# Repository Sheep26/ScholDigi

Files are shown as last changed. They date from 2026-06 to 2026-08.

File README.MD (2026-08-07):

# Why am I requesting funding again.
I am requesting funding again so I would be able to get a second revision of my board printed. I will mostly not be using PCBA so it'll be cheaper.  
The reason I need a second revision is because of my mistakes/errors, I left a few things out on the board (and also had a short which killed the GPS module).  
So I am requesting the funding for a new GPS module and to get a new board printed with space for more resistors, capacitors and more which I will solder myself.

# Scholarship Digitech.
This is my NZQA scholarship technology project.  
It is a small device which can fit in your pocket or bag, and will track your tramping, hiking, walking, running, cycling, skiing, etc.  
It uses a Ublox max-m10s gpu module on a fully custom pcb, with an esp32-c6, battery management system, power management system, serial connection and 2 usb ports for 2 different reasons (one is charging the other is flashing firmware which can also be done from testpoints in case there is too much signal interference).    

This project took inspration from apps such as Strava, however it aims to tackle one of the main issues with Strava which is the fact that it uses your phone. Strava is known to drain phone batteries and on many phones just not work well, this project aims to replace it with a dedicated device with a high accuracy GPS and long battery life allowing it to combat the various issues with fitness apps such as Strava.    

The purpose of this project, was to make an open source fitness tracker for cheap. The point is the motivate communities to improve their fitness and wellbeing without having them spend hundreds of dollars on something like a Garmin or Samsung smart watch and for it to be easy. Something small you can put in your pocket or bag which can last a long time on battery.  

## Hardware
Microcontroller | ESP32-C6-Mini  
GPS | Ublox MAX-M10S GPS module  
Battery management | TP4056 lithium battery charger  
Power management | TPS63060 voltage step down or step up buck converter  
CP2102 | Serial UART to USB  

(For a full list of hardware and pricing visit the BOM)



## Render
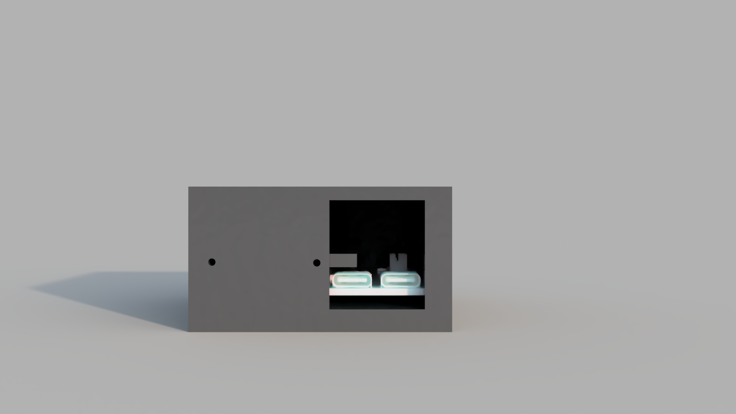
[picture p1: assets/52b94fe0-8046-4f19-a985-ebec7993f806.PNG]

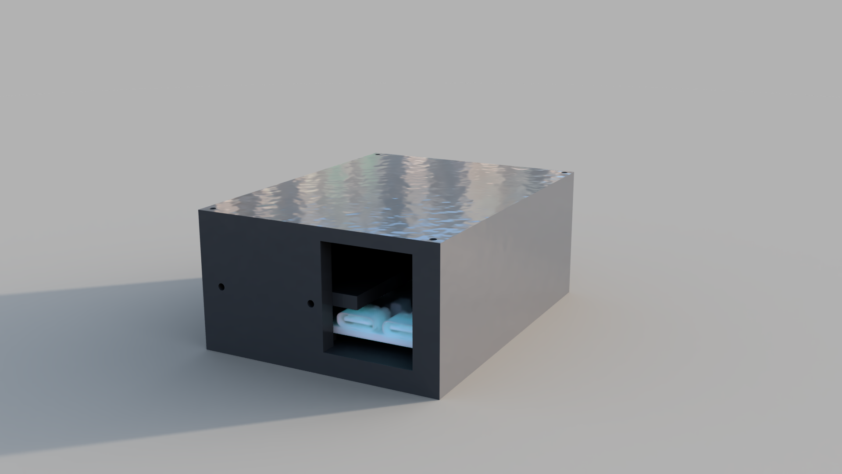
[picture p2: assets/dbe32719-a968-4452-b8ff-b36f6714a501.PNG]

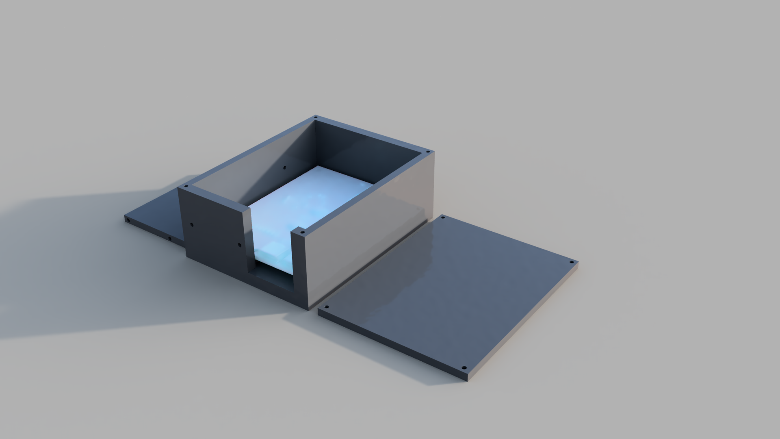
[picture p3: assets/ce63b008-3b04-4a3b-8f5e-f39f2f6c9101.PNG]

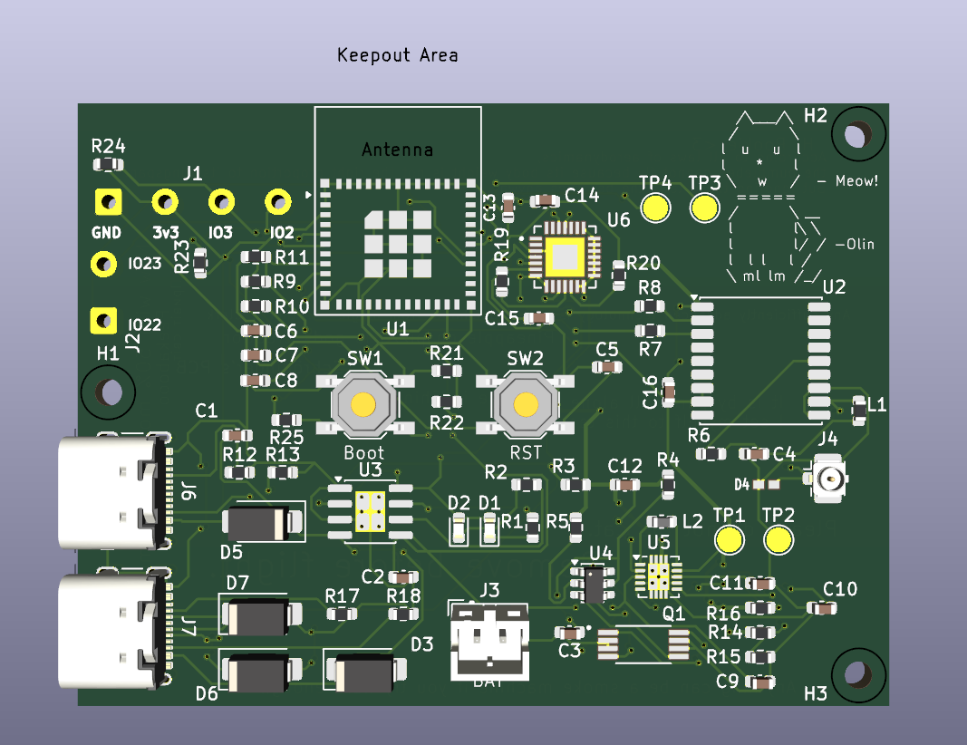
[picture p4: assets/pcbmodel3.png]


## Schematic
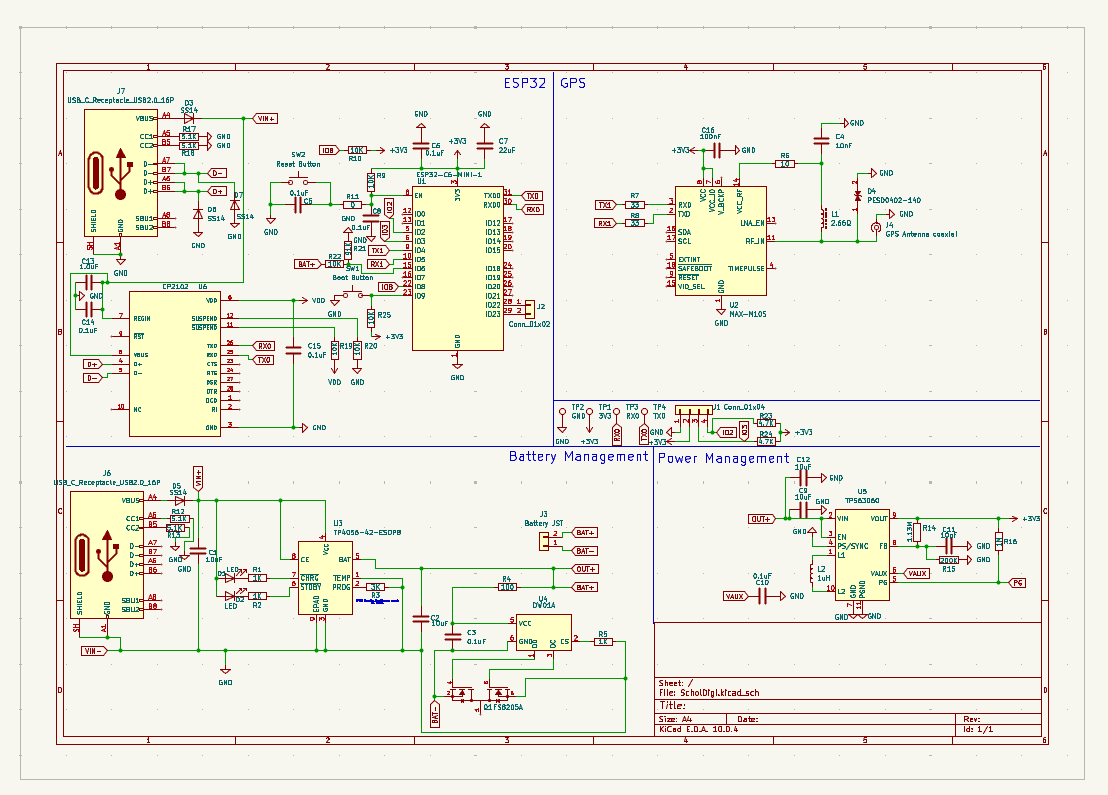
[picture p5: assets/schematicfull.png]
Schematic Image 1


## PCB
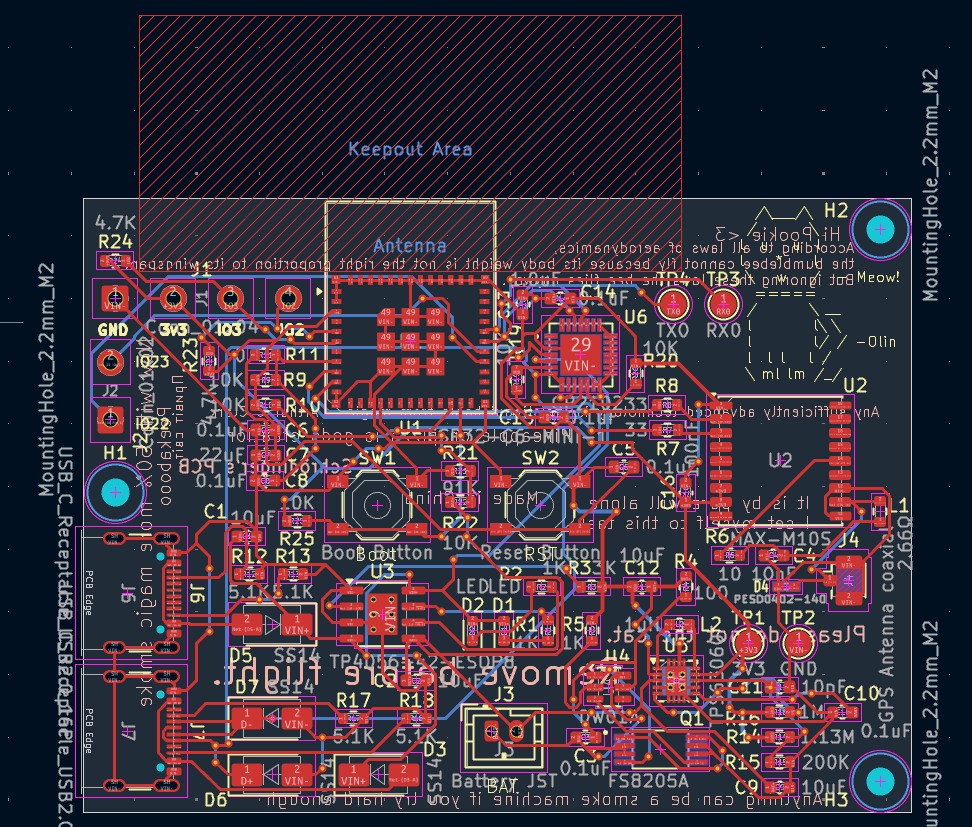
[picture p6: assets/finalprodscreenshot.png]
PCB Image 1


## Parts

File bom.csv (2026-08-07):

Type | PART | Qty | Source | Total Price ($)
PCB |  | 5 | JLCPCB | 2
PCBA |  | 5 | JLCPCB | 10.87
PCBTOTAL |  | 5 | JLCPCB | 12.87
SHIPPING |  | 1 | DHL EXPRESS | 16
PART | 1 | UBLOX MAX-M10S-00B | DIGIKEY | 12.29
SHIPPING | 1 |  | DHL EXPRESS | 15.23
GST | 1 |  |  | 4.13
PARTTOTAL |  |  |  | 31.68
TOTAL |  |  |  | 60.55

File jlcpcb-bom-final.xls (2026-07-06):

Comment | Designator | Footprint | JLCPCB Part # | Qty | Ext.Price($)
10nF | C4 | 0603 | C57112 | 20 | 0.16
10pF | C11 | 0603 | C1634 | 20 | 0.12
2.66Ω | L1 | 0603 | C113030 | 10 | 0.84
GPSAntennacoaxial | J4 | SMD | C88374 | 5 | 0.54
33 | R7,R8 | 0603 | C23140 | 20 | 0.04
0.1uF | C10,C14,C15,C3,C5,C6,C8 | 0603 | C14663 | 24 | 0.64
BatteryJST | J3 | 插件,P=2mm | C131337 | 3 | 0.10
USB_C_Receptacle_USB2.0_16P | J6,J7 | SMD | C5184243 | 4 | 4.64
LED | D1,D2 | 0603 | C2290 | 20 | 0.24
1uH | L2 | 0603 | C2839970 | 20 | 0.45
10uF | C1,C12,C2,C9 | 0603 | C19702 | 20 | 2.10
ResetButton | SW1,SW2 | SMD-4P,5.2x5.2mm | C2886894 | 4 | 2.68
CP2102 | U6 | - | C6568 | 2 | 4.39
PESD0402-140 | D4 | 0402 | C10662 | 5 | 0.71
SS14 | D3,D5,D6,D7 | SMA(DO-214AC) | C2480 | 18 | 0.32
10K | R10,R19,R20,R22,R9 | 0603 | C95204 | 20 | 0.59
200K | R15 | 0603 | C25811 | 20 | 0.05
5.1K | R12,R13,R17,R18 | 0603 | C23186 | 20 | 0.06
10 | R6 | 0603 | C22859 | 20 | 0.05
100 | R4 | 0603 | C22775 | 20 | 0.41
MAX-M10S | U2 | LCC-18(9.7x10.1) | C4153167 | 2 | 19.86
TP4056-42-ESOP8 | U3 | ESOP-8 | C16581 | 2 | 0.37
1.13M | R14 | 0603 | C166907 | 20 | 0.04
91K | R21 | 0603 | C101235 | 20 | 0.03
1M | R16 | 0603 | C22935 | 20 | 0.05
22uF | C7 | 0603 | C59461 | 20 | 0.68
1.0uF | C13 | 0603 | C15849 | 20 | 2.61
3K | R3 | 0603 | C4211 | 20 | 0.05
ESP32-C6-MINI-1 | U1 | SMD-53P | C5736265 | 2 | 7.43
DW01A | U4 | SOT23-6 | C18164398 | 10 | 0.24
0 | R11 | 0603 | C21189 | 20 | 0.06
1K | R1,R2,R5 | 0603 | C21190 | 20 | 0.05
TPS63060 | U5 | WSON-10-EP(3x3) | C48567 | 2 | 5.36

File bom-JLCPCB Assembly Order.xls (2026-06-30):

JLCPCB BOM Tool - BOM Matching
BOM name：bom-JLCPCB Assembly Order.xlsx |  |  | Download Time：2026-06-26 19:02:52 |  |  |  | * Our matching results are updated in real-time, but stock and prices may change. If it's been over 24 hours, please re-match before placing your order.
PCB Assembled Qty：5 |  |  | Est. Total Price：139.7647
Your BOM |  |  |  |  | Matched Parts |  |  |  |  |  |  | Order Information
Top Designator | Bottom Designator | Comment | Footprint | JLCPCB Part # | Matches | Part # | Manufacturer | Footprint | Description | Category | Warning | JLCPCB Part # | Product link | Lib Type | Qty | Source | Total Price ($)
C1,C12,C2,C9 |  | 10uF | 0603 |  | Select by System | CL10A106KP8NNNC | Samsung Electro-Mechanics | 0603 | 10V 10uF X5R ±10% 0603 Multilayer Ceramic Capacitors MLCC - SMD/SMT ROHS | Multilayer Ceramic Capacitors MLCC - SMD/SMT |  | C19702 | https://jlcpcb.com/partdetail/20411-CL10A106KP8NNNC/C19702 | Basic | 30 | 30 JLCPCB | 1.734
C4 |  | 10nF | 0603 |  | Select by System | 0603B103K500NT | FH (Guangdong Fenghua Advanced Tech) | 0603 | 10nF 50V X7R ±10% 0603 Multilayer Ceramic Capacitors MLCC - SMD/SMT ROHS | Multilayer Ceramic Capacitors MLCC - SMD/SMT |  | C57112 | https://jlcpcb.com/partdetail/58143-0603B103K500NT/C57112 | Basic | 20 | 20 JLCPCB | 0.36
C7 |  | 22uF | 0603 |  | Select by System | CL10A226MQ8NRNC | Samsung Electro-Mechanics | 0603 | 22uF 6.3V X5R ±20% 0603 Multilayer Ceramic Capacitors MLCC - SMD/SMT ROHS | Multilayer Ceramic Capacitors MLCC - SMD/SMT |  | C59461 | https://jlcpcb.com/partdetail/60514-CL10A226MQ8NRNC/C59461 | Basic | 20 | 20 JLCPCB | 0.47
C10,C14,C15,C3,C5,C6,C8 |  | 0.1uF | 0603 |  | Unconfirmed | CC0603KRX7R9BB104 | YAGEO | 0603 | 100nF 50V X7R ±10% 0603 Multilayer Ceramic Capacitors MLCC - SMD/SMT ROHS | Multilayer Ceramic Capacitors MLCC - SMD/SMT | 1.The comment (CC0603KRX7R9BB104) of this part does not match the one (0.1uF) provided in your BOM. Please confirm; | C14663 | https://jlcpcb.com/partdetail/YAGEO-CC0603KRX7R9BB104/C14663 | Basic | 45 | 45 JLCPCB | 0.486
C11 |  | 10pF | 0603 |  | Select by System | CL10C100JB8NNNC | Samsung Electro-Mechanics | 0603 | 10pF 50V C0G ±5% 0603 Multilayer Ceramic Capacitors MLCC - SMD/SMT ROHS | Multilayer Ceramic Capacitors MLCC - SMD/SMT |  | C1634 | https://jlcpcb.com/partdetail/1986-CL10C100JB8NNNC/C1634 | Basic | 20 | 20 JLCPCB | 0.118
C13 |  | 1.0uF | 0603 |  | Unconfirmed | CL10A105KB8NNNC | Samsung Electro-Mechanics | 0603 | 1uF 50V X5R ±10% 0603 Multilayer Ceramic Capacitors MLCC - SMD/SMT ROHS | Multilayer Ceramic Capacitors MLCC - SMD/SMT | 1.The comment (CL10A105KB8NNNC) of this part does not match the one (1.0uF) provided in your BOM. Please confirm; | C15849 | https://jlcpcb.com/partdetail/16531-CL10A105KB8NNNC/C15849 | Basic | 20 | 20 JLCPCB | 0.308
D1,D2 |  | LED | 0603 |  | Unconfirmed | KT-0603W | Hubei KENTO Elec | 0603 | -40℃~+85℃ 100mW 120° 2.6V~3.1V 360mcd 5mA Discrete Diode Top-mount White Yellow Lens 0603 LED Indication - Discrete ROHS | LED Indication - Discrete | 1.The comment (KT-0603W) of this part does not match the one (LED) provided in your BOM. Please confirm; | C2290 | https://jlcpcb.com/partdetail/Hubei_KENTOElec-KT0603W/C2290 | Basic | 20 | 20 JLCPCB | 0.24
D3,D5,D6,D7 |  | SS14 | D_SMA |  | Select by System | SS14 | MDD(Microdiode Semiconductor) | SMA(DO-214AC) | -55℃~+150℃ 1A 25A 300uA@40V 40V 550mV@1A Independent SMA(DO-214AC) Schottky Diodes ROHS | Schottky Diodes |  | C2480 | https://jlcpcb.com/partdetail/MDD_Microdiode_Semiconductor-SS14/C2480 | Basic | 30 | 30 JLCPCB | 0.501
D4 |  | PESD0402-140 | DIO_PESD0402-140 |  | Select by Customer | PESD0402-140 | Littelfuse | 0402 | -55℃~+125℃ 0.25pF 10uA 14V 40V Bidirectional ESD IEC 61000-4-2 0402 ESD and Surge Protection (TVS/ESD) ROHS | ESD And Surge Protection (TVS/ESD) |  | C10662 | https://jlcpcb.com/partdetail/Littelfuse-PESD0402140/C10662 | Extended | 8 | 8 JLCPCB | 1.0552
J3 |  | BatteryJST | JST_PH_B2B-PH-K_1x02_P2.00mm_Vertical |  | Select by Customer | B2B-PH-K-S(LF)(SN) | JST | 插件,P=2mm | -25℃~+85℃ 1 100V 1x2P 2 2A 2P 2mm 4.5mm 5.9mm 6mm Brass K Pin PA66 PH Through Hole Tin UL94V-0 White 插件,P=2mm Wire To Board Connector ROHS | Wire To Board Connector |  | C131337 | https://jlcpcb.com/partdetail/JST-B2B_PH_K_S_LF_SN/C131337 | Extended | 6 | 6 JLCPCB | 0.2076
J4 |  | GPSAntennacoaxial | U.FL_Hirose_U.FL-R-SMT-1_Vertical |  | Select by Customer | U.FL-R-SMT-1(80) | HRS(Hirose) | SMD | -40℃~+90℃ 1 1.25mm 2mm 50Ω 6GHz Board Side IPEX Male Pin SMD Coaxial Connectors (RF) ROHS | Coaxial Connectors (RF) |  | C88374 | https://jlcpcb.com/partdetail/HRS_Hirose-U_FL_R_SMT_1_80/C88374 | Extended | 7 | 7 JLCPCB | 0.7511
J6,J7 |  | USB_C_Receptacle_USB2.0_16P | USB_C_Receptacle_GCT_USB4105-xx-A_16P_TopMnt_Horizontal |  | Select by Customer | USB4105-GF-A-120 | Global Connector Technology | SMD | -40℃~+85℃ 1 16P 48V 5A Black Female Type-C USB 2.0 SMD USB Connectors ROHS | USB Connectors |  | C5184243 | https://jlcpcb.com/partdetail/5849584-USB4105_GF_A120/C5184243 | Extended | 10 | 10 JLCPCB | 9.361
L1 |  | 2.66Ω | 0603 |  | Select by Customer | BLM18SG121TN1D | Murata Electronics | 0603 | 1 120Ω@100MHz 25mΩ 3A ±25% 0603 Ferrite Beads ROHS | Ferrite Beads |  | C113030 | https://jlcpcb.com/partdetail/MurataElectronics-BLM18SG121TN1D/C113030 | Extended | 13 | 13 JLCPCB | 1.0842
L2 |  | 1uH | 0603 |  | Select by System | YL160808-1R0K | YJYCOIN | 0603 | 1uH 25mA 35@10MHz 600mΩ 75MHz ±10% 0603 Inductors (SMD) ROHS | Inductors (SMD) |  | C2839970 | https://jlcpcb.com/partdetail/YJYCOIN-YL1608081R0K/C2839970 | Extended | 20 | 20 JLCPCB | 0.438
Q1 |  | FS8205A | SOP65P640X120-8N |  | Select by System | FS8205A | TECH PUBLIC | SOT-23-6 | -55℃~+150℃ 1.2V 1.5W 2 N-Channel 20V 31.5mΩ@2.5V 466pF 5.7nC@4.5V 58pF 65pF 6A SOT-23-6 MOSFETs ROHS | MOSFETs |  | C2830320 | https://jlcpcb.com/partdetail/TECHPUBLIC-FS8205A/C2830320 | Extended | 9 | 9 JLCPCB | 0.5076
R1,R2,R5 |  | 1K | 0603 |  | Unconfirmed | 0603WAF1001T5E | UNI-ROYAL(Uniroyal Elec) | 0603 | -55℃~+155℃ 100mW 1kΩ 75V Thick Film Resistor ±1% ±100ppm/℃ 0603 Chip Resistor - Surface Mount ROHS | Chip Resistor - Surface Mount | 1.The comment (0603WAF1001T5E) of this part does not match the one (1K) provided in your BOM. Please confirm; | C21190 | https://jlcpcb.com/partdetail/21904-0603WAF1001T5E/C21190 | Basic | 25 | 25 JLCPCB | 0.12
R3 |  | 3K | 0603 |  | Unconfirmed | 0603WAF3001T5E | UNI-ROYAL(Uniroyal Elec) | 0603 | -55℃~+155℃ 100mW 3kΩ 75V Thick Film Resistor ±1% ±100ppm/℃ 0603 Chip Resistor - Surface Mount ROHS | Chip Resistor - Surface Mount | 1.The comment (0603WAF3001T5E) of this part does not match the one (3K) provided in your BOM. Please confirm; | C4211 | https://jlcpcb.com/partdetail/4618-0603WAF3001T5E/C4211 | Basic | 20 | 20 JLCPCB | 0.038
R4 |  | 100 | 0603 |  | Unconfirmed | 0603WAF1000T5E | UNI-ROYAL(Uniroyal Elec) | 0603 | -55℃~+155℃ 100mW 100Ω 75V Thick Film Resistor ±1% ±100ppm/℃ 0603 Chip Resistor - Surface Mount ROHS | Chip Resistor - Surface Mount | 1.The comment (0603WAF1000T5E) of this part does not match the one (100) provided in your BOM. Please confirm; | C22775 | https://jlcpcb.com/partdetail/23502-0603WAF1000T5E/C22775 | Basic | 20 | 20 JLCPCB | 0.064
R6 |  | 10 | 0603 |  | Unconfirmed | 0603WAF100JT5E | UNI-ROYAL(Uniroyal Elec) | 0603 | -55℃~+155℃ 100mW 10Ω 75V Thick Film Resistor ±1% ±400ppm/℃ 0603 Chip Resistor - Surface Mount ROHS | Chip Resistor - Surface Mount | 1.The comment (0603WAF100JT5E) of this part does not match the one (10) provided in your BOM. Please confirm; | C22859 | https://jlcpcb.com/partdetail/23586-0603WAF100JT5E/C22859 | Basic | 20 | 20 JLCPCB | 0.05
R7,R8 |  | 33 | 0603 |  | Unconfirmed | 0603WAF330JT5E | UNI-ROYAL(Uniroyal Elec) | 0603 | -55℃~+155℃ 100mW 33Ω 75V Thick Film Resistor ±1% ±100ppm/℃ 0603 Chip Resistor - Surface Mount ROHS | Chip Resistor - Surface Mount | 1.The comment (0603WAF330JT5E) of this part does not match the one (33) provided in your BOM. Please confirm; | C23140 | https://jlcpcb.com/partdetail/23867-0603WAF330JT5E/C23140 | Basic | 20 | 20 JLCPCB | 0.034
R10,R19,R20,R22,R9 |  | 10K | 0603 |  | Unconfirmed | 0603WAF1002T5E | UNI-ROYAL(Uniroyal Elec) | 0603 | -55℃~+155℃ 100mW 10kΩ 75V Thick Film Resistor ±1% ±100ppm/℃ 0603 Chip Resistor - Surface Mount ROHS | Chip Resistor - Surface Mount | 1.The comment (0603WAF1002T5E) of this part does not match the one (10K) provided in your BOM. Please confirm; | C25804 | https://jlcpcb.com/partdetail/26547-0603WAF1002T5E/C25804 | Basic | 35 | 35 JLCPCB | 0.574
R11 |  | 0 | 0603 |  | Unconfirmed | 0603WAF0000T5E | UNI-ROYAL(Uniroyal Elec) | 0603 | -55℃~+155℃ 0Ω 100mW 75V Thick Film Resistor ±1% 0603 Chip Resistor - Surface Mount ROHS | Chip Resistor - Surface Mount | 1.The comment (0603WAF0000T5E) of this part does not match the one (0) provided in your BOM. Please confirm; | C21189 | https://jlcpcb.com/partdetail/21903-0603WAF0000T5E/C21189 | Basic | 20 | 20 JLCPCB | 0.044
R12,R13,R17,R18 |  | 5.1K | 0603 |  | Unconfirmed | 0603WAF5101T5E | UNI-ROYAL(Uniroyal Elec) | 0603 | -55℃~+155℃ 100mW 5.1kΩ 75V Thick Film Resistor ±1% ±100ppm/℃ 0603 Chip Resistor - Surface Mount ROHS | Chip Resistor - Surface Mount | 1.The comment (0603WAF5101T5E) of this part does not match the one (5.1K) provided in your BOM. Please confirm; | C23186 | https://jlcpcb.com/partdetail/23913-0603WAF5101T5E/C23186 | Basic | 30 | 30 JLCPCB | 0.06
R14 |  | 1.13M | 0603 |  | Unconfirmed | RTT031134FTP | RALEC | 0603 | -55℃~+155℃ 1.13MΩ 100mW 75V Thick Film Resistor ±1% ±100ppm/℃ 0603 Chip Resistor - Surface Mount ROHS | Chip Resistor - Surface Mount | 1.The comment (RTT031134FTP) of this part does not match the one (1.13M) provided in your BOM. Please confirm; | C166907 | https://jlcpcb.com/partdetail/RALEC-RTT031134FTP/C166907 | Extended | 20 | 20 JLCPCB | 0.042
R15 |  | 200K | 0603 |  | Unconfirmed | 0603WAF2003T5E | UNI-ROYAL(Uniroyal Elec) | 0603 | -55℃~+155℃ 100mW 200kΩ 75V Thick Film Resistor ±1% ±100ppm/℃ 0603 Chip Resistor - Surface Mount ROHS | Chip Resistor - Surface Mount | 1.The comment (0603WAF2003T5E) of this part does not match the one (200K) provided in your BOM. Please confirm; | C25811 | https://jlcpcb.com/partdetail/26554-0603WAF2003T5E/C25811 | Basic | 20 | 20 JLCPCB | 0.042
R16 |  | 1M | 0603 |  | Unconfirmed | 0603WAF1004T5E | UNI-ROYAL(Uniroyal Elec) | 0603 | -55℃~+155℃ 100mW 1MΩ 75V Thick Film Resistor ±1% ±100ppm/℃ 0603 Chip Resistor - Surface Mount ROHS | Chip Resistor - Surface Mount | 1.The comment (0603WAF1004T5E) of this part does not match the one (1M) provided in your BOM. Please confirm; | C22935 | https://jlcpcb.com/partdetail/23662-0603WAF1004T5E/C22935 | Basic | 20 | 20 JLCPCB | 0.046
R21 |  | 91K | 0603 |  | Select by Customer | CR0603FA9102G | LIZ Elec | 0603 | -55℃~+125℃ 100mW 50V 91kΩ Thick Film Resistor ±1% ±100ppm/℃ 0603 Chip Resistor - Surface Mount ROHS | Chip Resistor - Surface Mount | 1.The comment (CR0603FA9102G) of this part does not match the one (91K) provided in your BOM. Please confirm; | C101235 | https://jlcpcb.com/partdetail/LIZElec-CR0603FA9102G/C101235 | Extended | 20 | 20 JLCPCB | 0.03
SW1 |  | BootButton | SW_SPST_TL3342 |  | Select by Customer | TL3342F260QG | E-Switch | SMD-4P,5.2x5.2mm | -20℃~+70℃ 1.54mm 100,000 cycles 12V 2.6N 5.2mm 5.2mm 50mA Gull Wing Round Button SPST Surface Mount,Vertical Without Bracket Yellow SMD-4P,5.2x5.2mm Tactile Switches ROHS | Tactile Switches | 1.Multiple lines in the BOM have been matched to the same part. Please check if the matching is correct. ; | C2886894 | https://jlcpcb.com/partdetail/ESwitch-TL3342F260QG/C2886894 | Extended | 10 | 10 JLCPCB | 6.551
SW2 |  | ResetButton | SW_SPST_TL3342 |  | Select by Customer | TL3342F260QG | E-Switch | SMD-4P,5.2x5.2mm | -20℃~+70℃ 1.54mm 100,000 cycles 12V 2.6N 5.2mm 5.2mm 50mA Gull Wing Round Button SPST Surface Mount,Vertical Without Bracket Yellow SMD-4P,5.2x5.2mm Tactile Switches ROHS | Tactile Switches | 1.Multiple lines in the BOM have been matched to the same part. Please check if the matching is correct. ; | C2886894 | https://jlcpcb.com/partdetail/ESwitch-TL3342F260QG/C2886894 | Extended | 10 | 10 JLCPCB | 6.551
U1 |  | ESP32-C6-MINI-1 | ESP32-C6-MINI-1 |  | Select by Customer | ESP32-C6-MINI-1-N4 | Espressif Systems | SMD-53P | -106dBm -40℃~+85℃ 2.4GHz 21dBm 354mA 3V~3.6V 71mA ESP32-C6FH4 On-board PCB Antenna UART、SPI、I2C、GPIO、I2S SMD-53P WiFi Modules ROHS | WiFi Modules | 1.The comment (ESP32-C6-MINI-1-N4) of this part does not match the one (ESP32-C6-MINI-1) provided in your BOM. Please confirm; | C5736265 | https://jlcpcb.com/partdetail/EspressifSystems-ESP32_C6_MINI_1N4/C5736265 | Extended | 5 | 5 JLCPCB | 18.5195
U2 |  | MAX-M10S | ublox_MAX |  | Select by Customer | MAX-M10S-00B | U-BLOX | LCC-18(9.7x10.1) | LCC-18(9.7x10.1) GNSS Modules ROHS | GNSS Modules | 1.The comment (MAX-M10S-00B) of this part does not match the one (MAX-M10S) provided in your BOM. Please confirm; | C4153167 | https://jlcpcb.com/partdetail/UBLOX-MAX_M10S00B/C4153167 | Extended | 5 | 5 JLCPCB | 49.5215
U3 |  | TP4056-42-ESOP8 | SOIC-8-1EP_3.9x4.9mm_P1.27mm_EP2.41x3.3mm_ThermalVias |  | Select by System | TP4056-42-ESOP8 | TOPPOWER(Nanjing Extension Microelectronics) | ESOP-8 | -40℃~+85℃ 1 1A 2uA 4.2V 4V~8V Charging IC Lithium Battery Support ESOP-8 Battery Management ROHS | Battery Management |  | C16581 | https://jlcpcb.com/partdetail/17264-TP4056_42ESOP8/C16581 | Extended | 5 | 5 JLCPCB | 0.928
U4 |  | DW01A | SOT-23-6 |  | Select by System | DW01A | HL | SOT23-6 | -40℃~+85℃ 1 1.5V~10V 2.5V 4.3V 700nA Lithium Battery Protection IC Support SOT23-6 Battery Management ROHS | Battery Management |  | C18164398 | https://jlcpcb.com/partdetail/HL-DW01A/C18164398 | Extended | 10 | 10 JLCPCB | 0.243
U5 |  | TPS63060 | Texas_S-PWSON-N10_ThermalVias |  | Unconfirmed | TPS63060DSCR | Texas Instruments | WSON-10-EP(3x3) | -40℃~+85℃@(TA)、-40℃~+125℃@(TJ) 1 2.2MHz~2.6MHz、2.4MHz 2.5V~12V 2.5V~8V 2A 30uA Adjustable Buck-Boost Buck-Boost Built-in Overcurrent Protection、Light load efficient mode、Load disconnect、Operating status indication、Frequency synchronization Yes WSON-10-EP(3x3) DC-DC Converters ROHS | DC-DC Converters | 1.The comment (TPS63060DSCR) of this part does not match the one (TPS63060) provided in your BOM. Please confirm; | C48567 | https://jlcpcb.com/partdetail/TexasInstruments-TPS63060DSCR/C48567 | Extended | 5 | 5 JLCPCB | 13.037
U6 |  | CP2102 | QFN50P500X500X100-29N |  | Select by System | CP2102 | Ai-Thinker | - | Non-isolated TYPE-A UART(TTL) USB2.0 - USB Conversion Modules ROHS | USB Conversion Modules |  | C192392 | https://jlcpcb.com/partdetail/AiThinker-CP2102/C192392 | Extended | 5 | 5 JLCPCB | 25.648
J2,J5,J8,J9 |  | Conn_01x01 | SolderWirePad_1x01_SMD_1x2mm |  | No matches | No Part Selected
TP1 |  | 3V3 | TestPoint_Pad_D2.0mm |  | No matches | No Part Selected
TP2 |  | GND | TestPoint_Pad_D2.0mm |  | No matches | No Part Selected
TP3 |  | RX0 | TestPoint_Pad_D2.0mm |  | No matches | No Part Selected
TP4 |  | TX0 | TestPoint_Pad_D2.0mm |  | No matches | No Part Selected

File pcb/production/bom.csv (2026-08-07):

Designator | Footprint | Quantity | Value | LCSC Part #
C1, C12, C2, C9 | 0603 | 4 | 10uF
C10, C14, C15, C3, C5, C6, C8 | 0603 | 7 | 0.1uF
C11 | 0603 | 1 | 10pF
C13 | 0603 | 1 | 1.0uF
C16 | 0603 | 1 | 100nF
C4 | 0603 | 1 | 10nF
C7 | 0603 | 1 | 22uF
D1, D2 | 0603 | 2 | LED
D3, D5, D6, D7 | D_SMA | 4 | SS14
D4 | DIO_PESD0402-140 | 1 | PESD0402-140
J1 | SolderWire-0.5sqmm_1x04_P4.6mm_D0.9mm_OD2.1mm | 1 | Conn_01x04
J2 | SolderWire-0.5sqmm_1x02_P4.6mm_D0.9mm_OD2.1mm | 1 | Conn_01x02
J3 | JST_PH_B2B-PH-K_1x02_P2.00mm_Vertical | 1 | Battery JST
J4 | U.FL_Hirose_U.FL-R-SMT-1_Vertical | 1 | GPS Antenna coaxial
J6, J7 | USB_C_Receptacle_GCT_USB4105-xx-A_16P_TopMnt_Horizontal | 2 | USB_C_Receptacle_USB2.0_16P
L1 | 0603 | 1 | 2.66Ω
L2 | 0603 | 1 | 1uH
Q1 | SOP65P640X120-8N | 1 | FS8205A
R1, R2, R5 | 0603 | 3 | 1K
R10, R19, R20, R22, R25, R9 | 0603 | 6 | 10K
R11 | 0603 | 1 | 0
R12, R13, R17, R18 | 0603 | 4 | 5.1K
R14 | 0603 | 1 | 1.13M
R15 | 0603 | 1 | 200K
R16 | 0603 | 1 | 1M
R21 | 0603 | 1 | 91K
R23, R24 | 0603 | 2 | 4.7K
R3 | 0603 | 1 | 3K
R4 | 0603 | 1 | 100
R6 | 0603 | 1 | 10
R7, R8 | 0603 | 2 | 33
SW1 | SW_SPST_TL3342 | 1 | Boot Button
SW2 | SW_SPST_TL3342 | 1 | Reset Button
TP1 | TestPoint_Pad_D2.0mm | 1 | 3V3
TP2 | TestPoint_Pad_D2.0mm | 1 | GND
TP3 | TestPoint_Pad_D2.0mm | 1 | RX0
TP4 | TestPoint_Pad_D2.0mm | 1 | TX0
U1 | ESP32-C6-MINI-1 | 1 | ESP32-C6-MINI-1
U2 | ublox_MAX | 1 | MAX-M10S
U3 | SOIC-8-1EP_3.9x4.9mm_P1.27mm_EP2.41x3.3mm_ThermalVias | 1 | TP4056-42-ESOP8
U4 | SOT-23-6 | 1 | DW01A
U5 | Texas_S-PWSON-N10_ThermalVias | 1 | TPS63060
U6 | QFN50P500X500X100-29N | 1 | CP2102

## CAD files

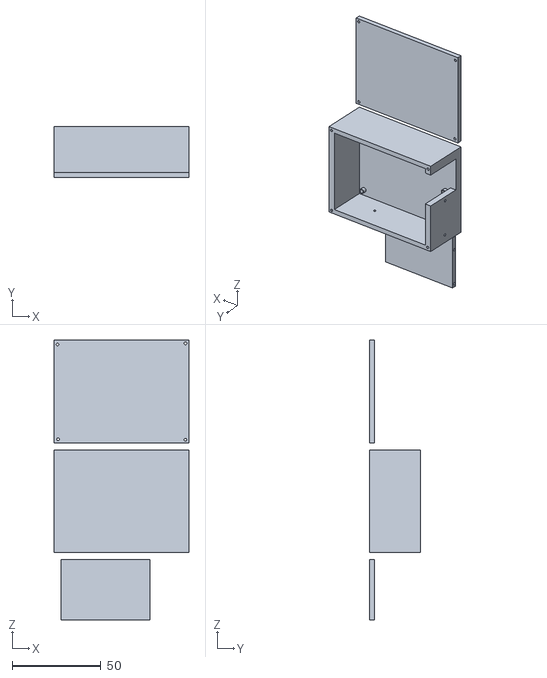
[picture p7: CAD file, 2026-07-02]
cad/case.stl
76.0 x 29.0 x 158.0

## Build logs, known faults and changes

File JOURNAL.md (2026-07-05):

## Entry 1 - 18/06/2026 - Time spent in session: 30 mins.
In this entry, we've designed a battery management and charging system in kicad schematic. It uses a TP4056 battery module and is designed for lithium batteries.  
We've picked a TP4056 lithium battery because it allows us to charge at upto 1 Amp (I shouldn't need more than that) and it's very simple to setup.
Image of kicad schematic  

## Entry 2 - 18/06/2026 - Time spent in session: 1 hour.
In this entry, we've designed the ESP32 and GPS module in the kicad schematic.  
The GPS module uses a Ublox max-m10s GPS module.  
I picked this module because it allows the same 4 constellation tracking as the Ublox neo-m9 module but because it updates slower, it uses much much less power. This allows us to get better battery life out of the same batteries which for a device like this which is designed for long tramps is very important for.  
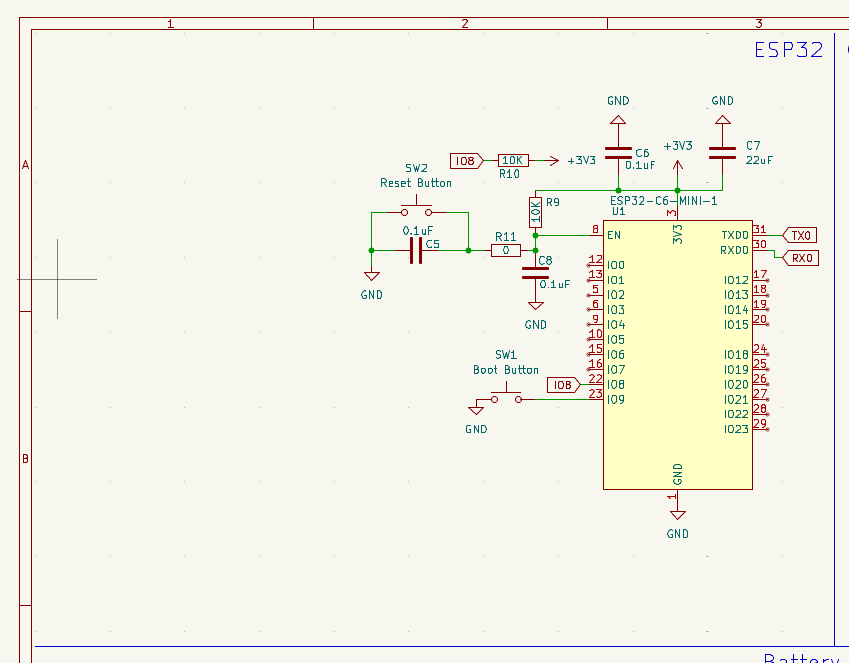
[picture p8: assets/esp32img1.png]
Image of esp32 kicad schematic
  
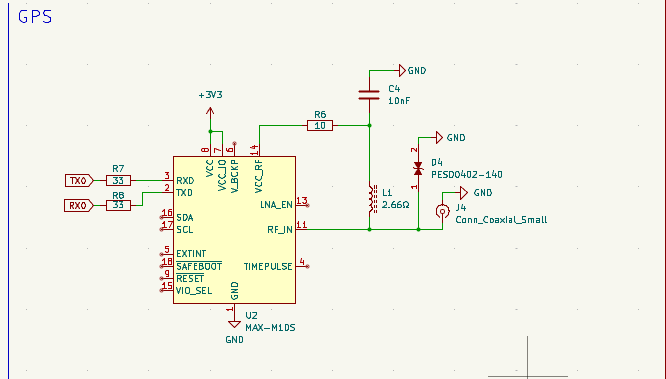
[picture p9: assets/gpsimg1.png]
Image of gps kicad schematic
  

## Entry 3 - 19/06/2026 - Time spent in session: 1 hour.
In this entry, we've designed the power management system from the batteries to power the rest of the PCB in the kicad schematic.  
It uses a TPS63060 module to either scale the voltage up to 3.3v or down to 3.3v. This allows us to not undervolt the PCB and not overvolt it and inevitably blow something.  
It uses a voltage dividor circut to maintain 3.3v.  
We also added a JST connector to the PCB to make it possible to connect a battery.  
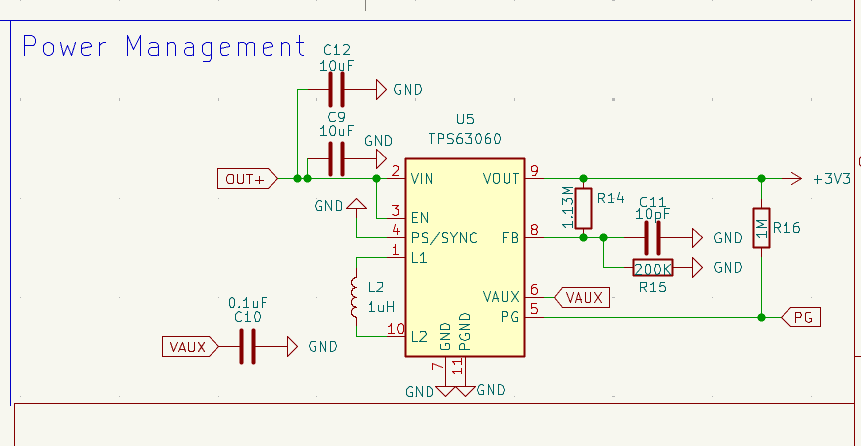
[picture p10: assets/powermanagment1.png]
Image of power management kicad schematic
  

## Entry 4 - 22/06/2026 - Time spent in session: 4 hours.
In this entry, we converted the schematic into an actual kicad PCB. This means it's no longer a plan, it can be an actual thing.  
I've placed all the components in their position. Organised the PCB and routed it.  
Also, I've added a CP2102 serial UART to usb chip to the PCB as well in this entry.  
This allows us to establish a serial connection to the ESP32 over USB instead of directly connecting to the RX0 and TX0 pins on the ESP32. This should make flashing firmware and debugging much easier, just incase, there are still testpoints on the board for RX0 and TX0.  
And I defined the Edge Cuts in the PCB in this entry as well.  
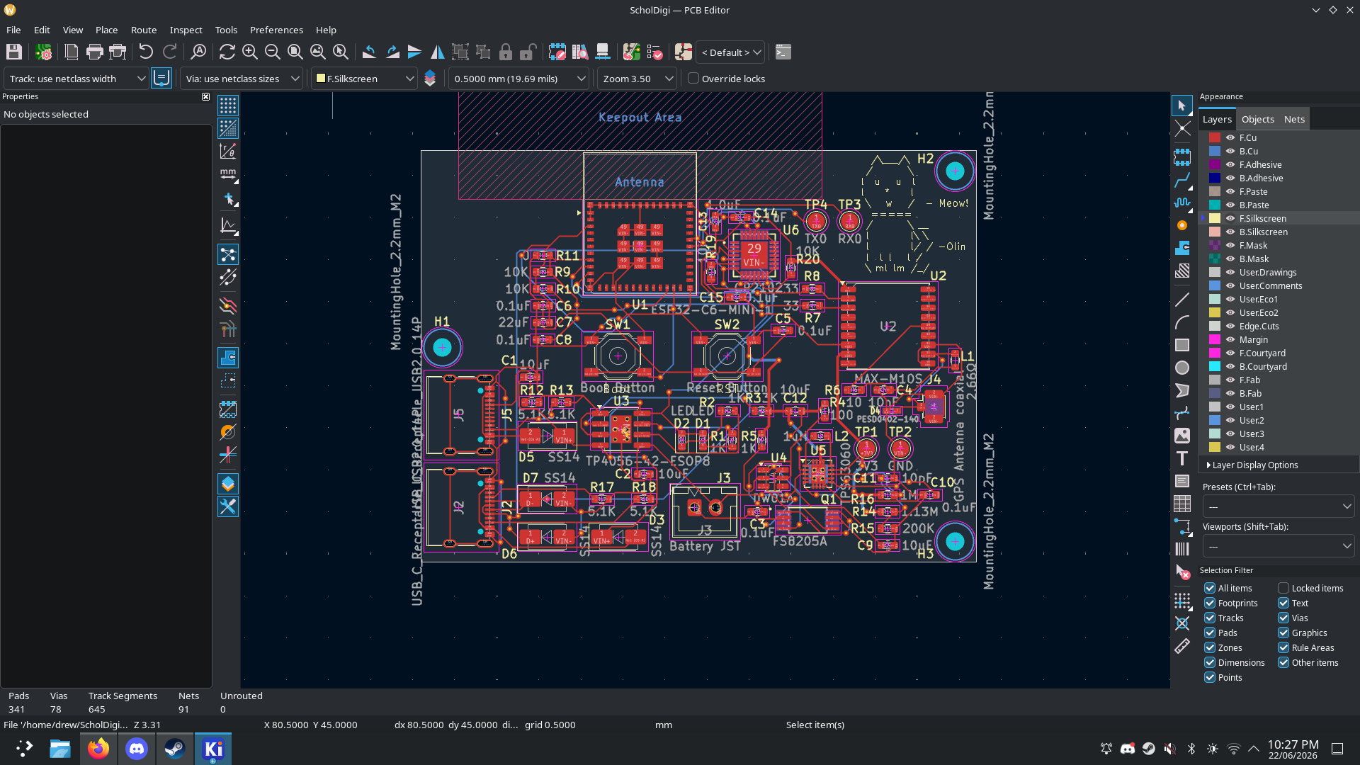
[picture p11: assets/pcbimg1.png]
  
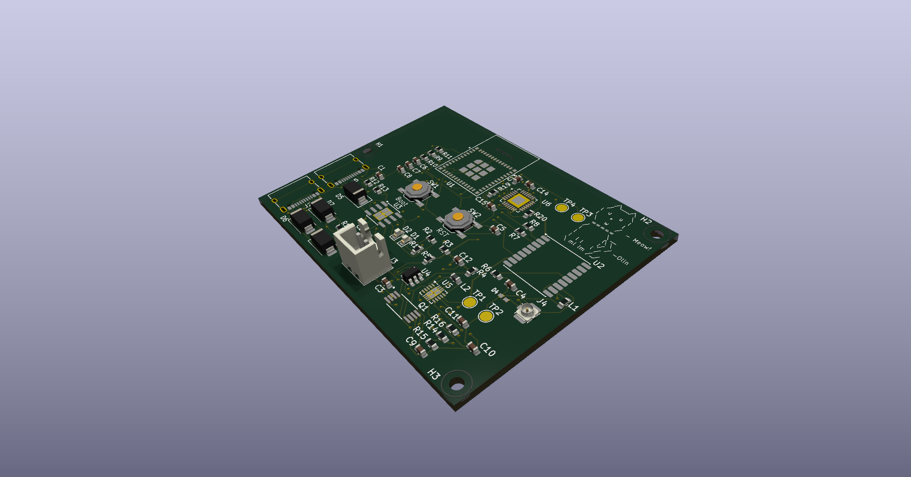
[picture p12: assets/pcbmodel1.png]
Image of 3D model of the PCB
  

## Entry 5 - 23/06/2026 - Time spent in session: 2 hours.
In this entry, I designed the case for the device in Fusion 360.  
It has space for the PCB and batteries. The only thing I haven't added in yet is space for the antenna which I'll cross that bridge after I get my hands on the PCB.  
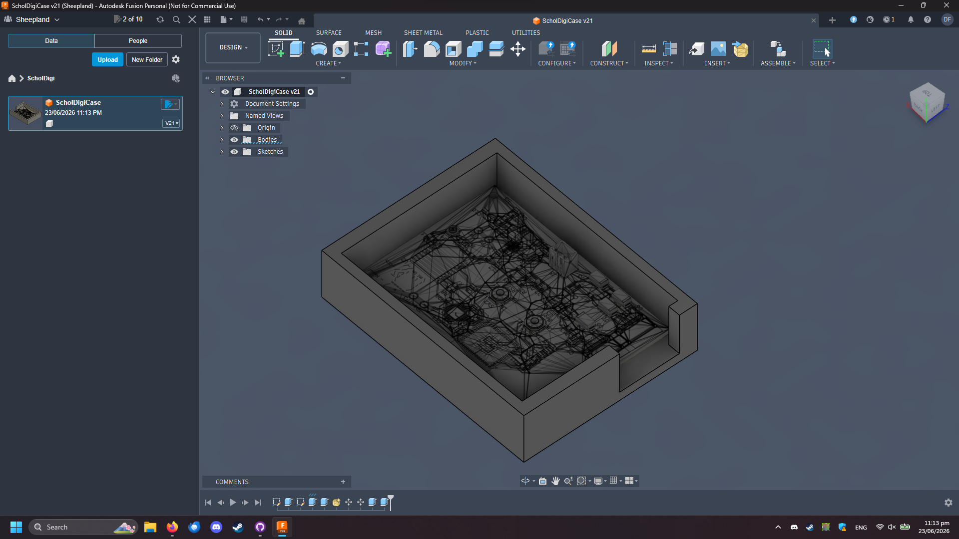
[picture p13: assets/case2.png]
Image of the case in Fusion 360
  
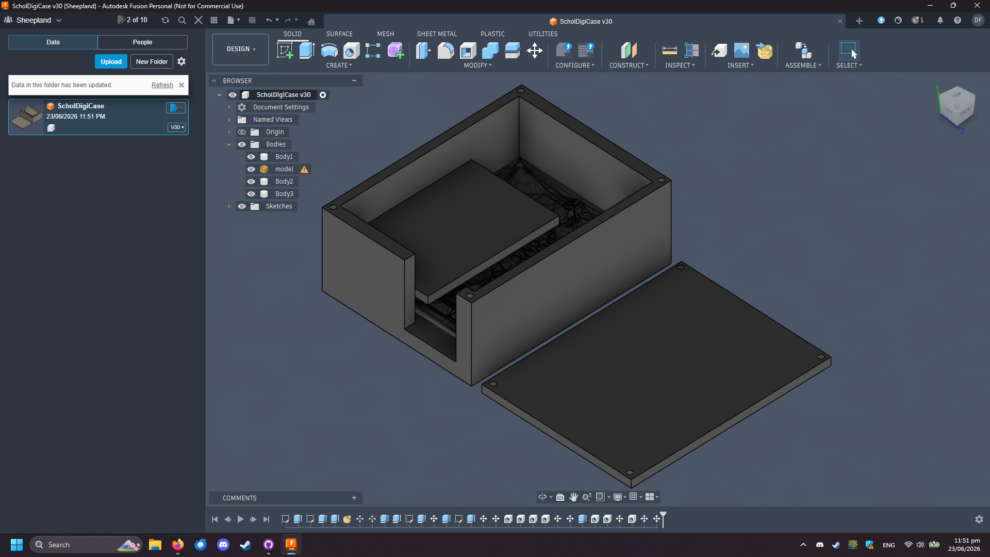
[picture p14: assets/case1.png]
Image of the case in Fusion 360
  

## Entry 6 - 25/06/2026 - Time spent in session: 30 mins.
In this entry, I added thru hole pins on the PCB board to allow us to connect and I2C OLED display to the ESP32 to run a display. I've been planning to run a 0.96" OLED display with the device to display basic statistics and info to the user.  
Image of the kicad PCB  

## Entry 7 - 26/06/2026 - Time spent in session: 1 hour.
In this entry, I added a voltage dividor from the battey JST to allow the ESP32 to measure the voltage of the battery.  
The reason I needed a voltage dividor is because a lithium battery can have it's voltage range from ~3v-4.2v depending on the remaining charge.  
If I put 4.2v straight into the GPIO pins of the ESP32, it would overvolt the ESP32 and blow something on it.
To prevent that, we run a 10x voltage divider on it (yes I know, very agressive) and this allows us to safely measure the voltage on the ESP32.  
I also swapped around some of the footprints due to part selection issues during fabrication (I've had a look at fabrication now because I wanted a quote from JLCPCB).  
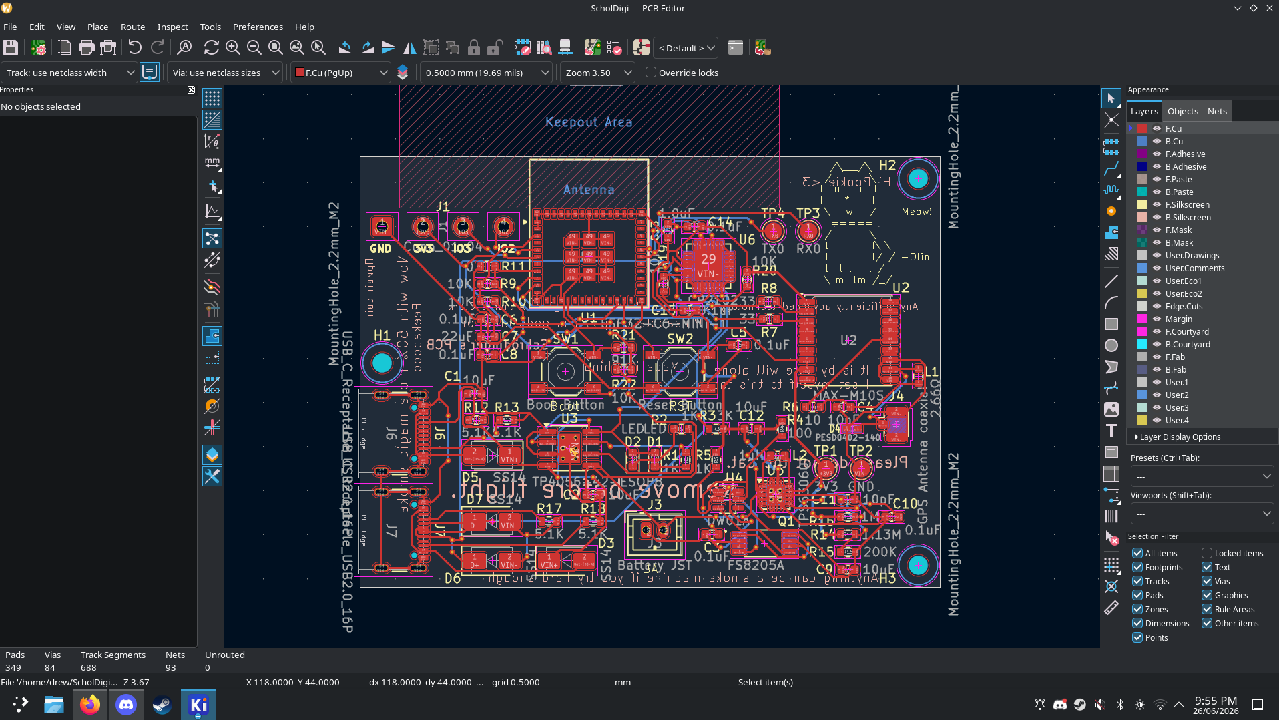
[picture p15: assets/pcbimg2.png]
  
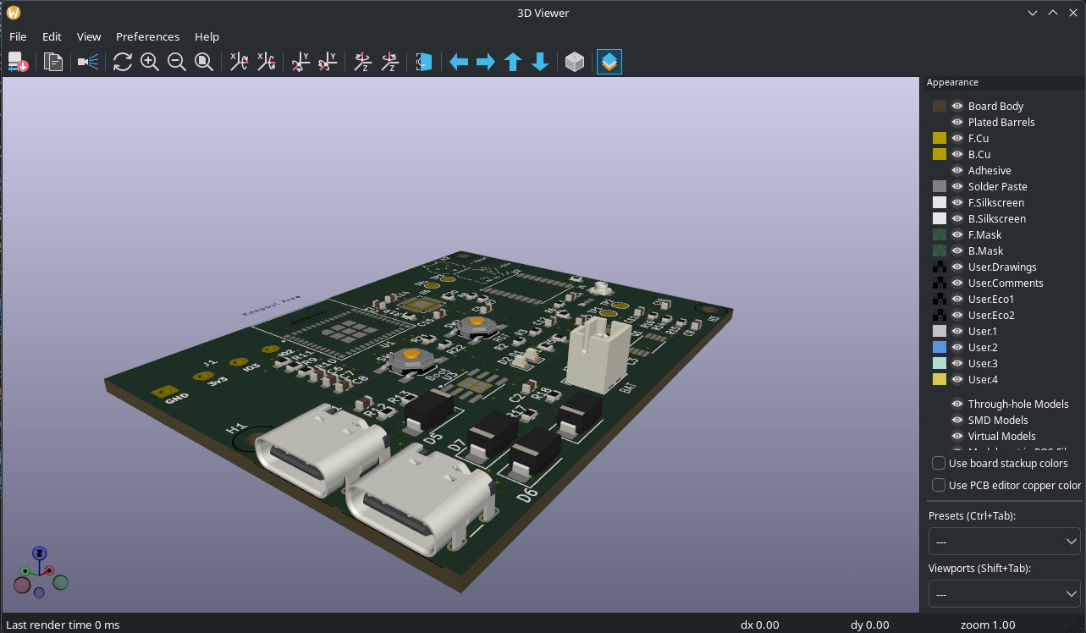
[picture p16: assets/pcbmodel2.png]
Image of 3D model of the PCB
  
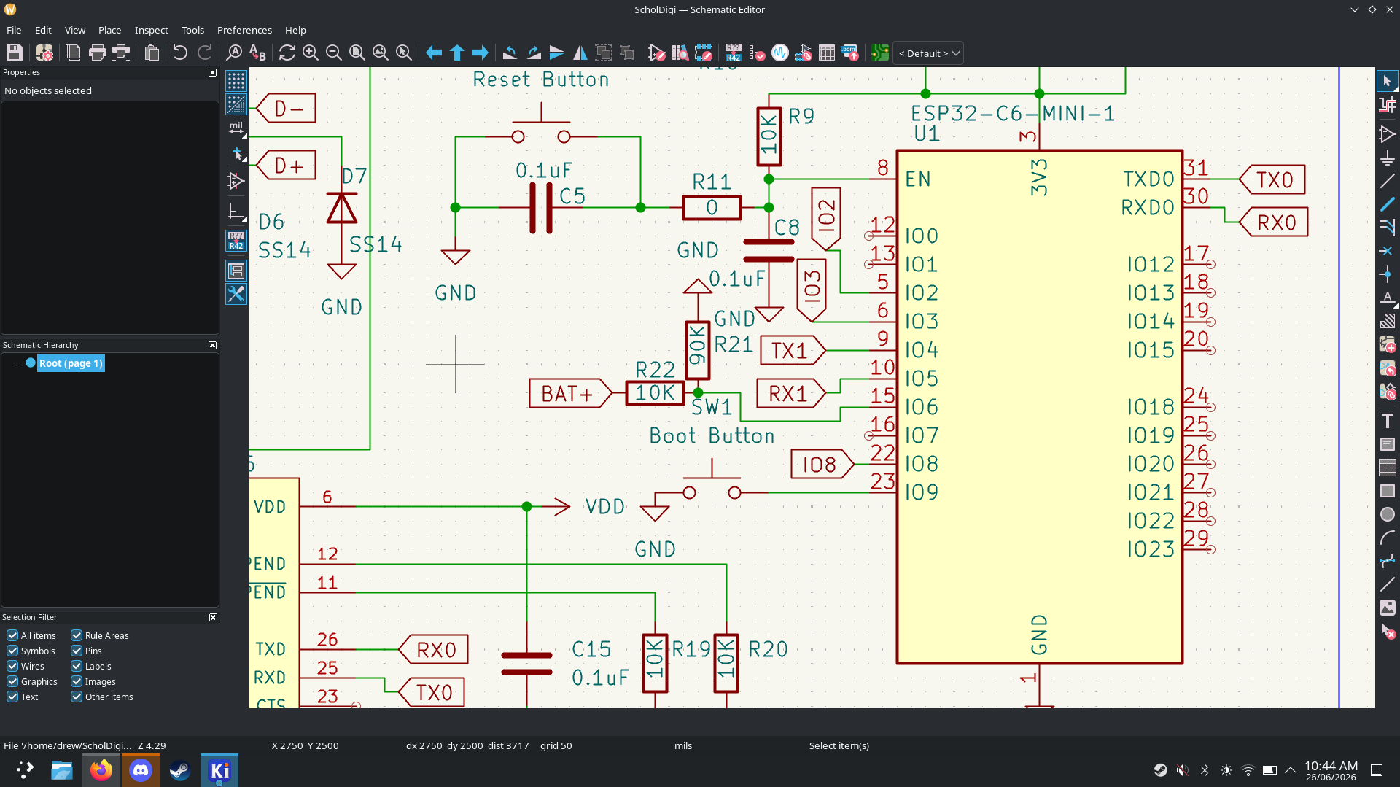
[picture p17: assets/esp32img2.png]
Image of the Voltage divider on the ESP32 in the schematic

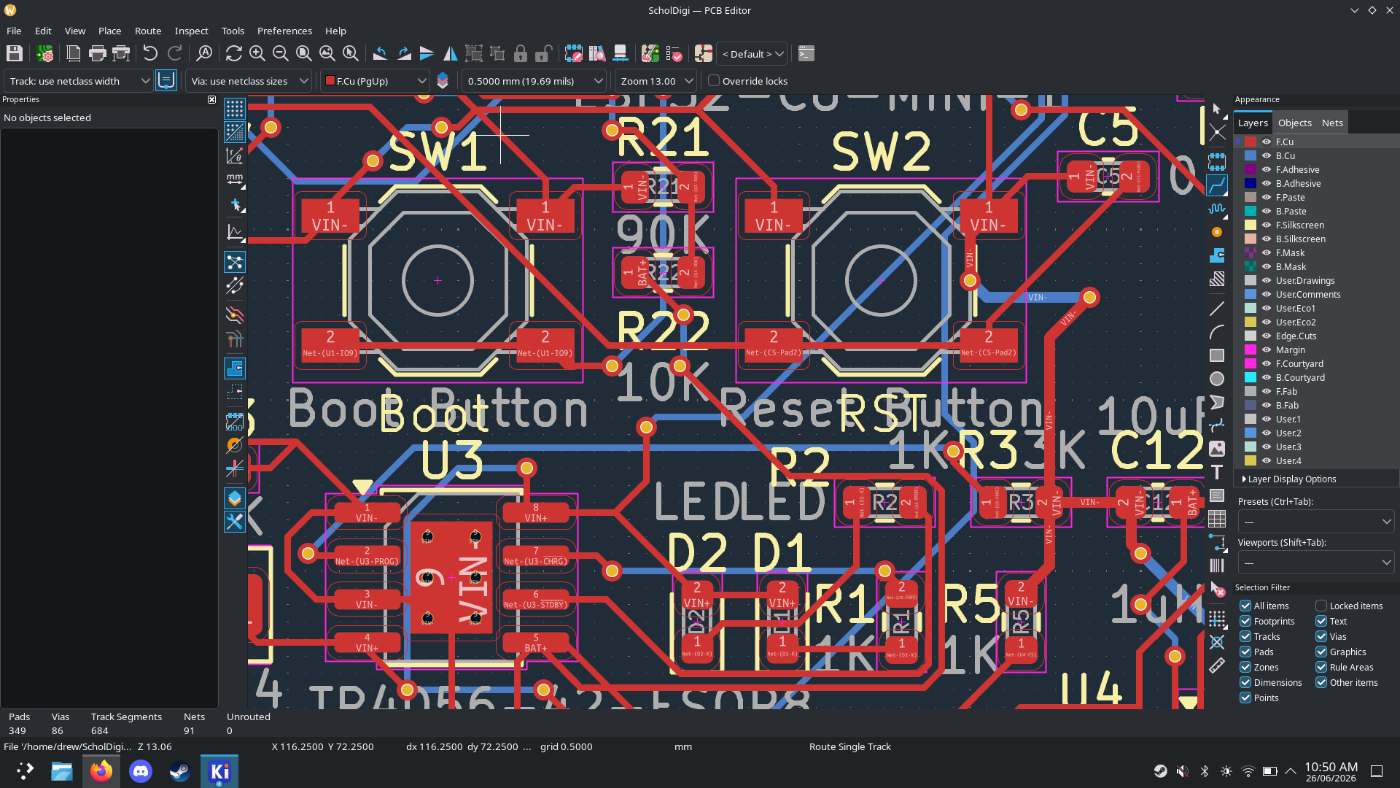
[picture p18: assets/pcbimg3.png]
Image of the Voltage divider on the ESP32 in the PCB
  

## Entry 8 - 01/07/2026 - Time spent in session: 1 hour.
In this entry, I've started making the firmware that the ESP32 will run.  
I've setup an ESP-IDF environment and copied over the hello world project.  
I also started to write the code for the connection to the GPS, I've setup TinyGPSPlus in the project and written a wrapper for it!  
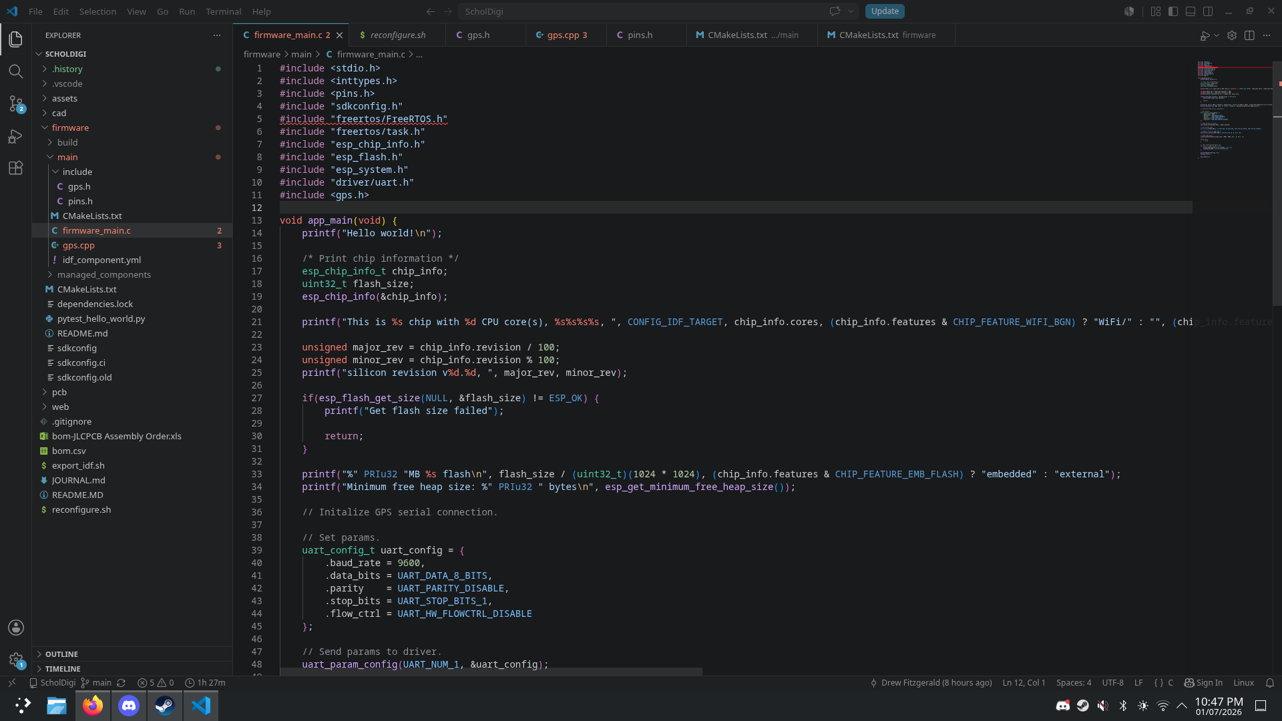
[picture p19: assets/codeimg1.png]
Code img1
  
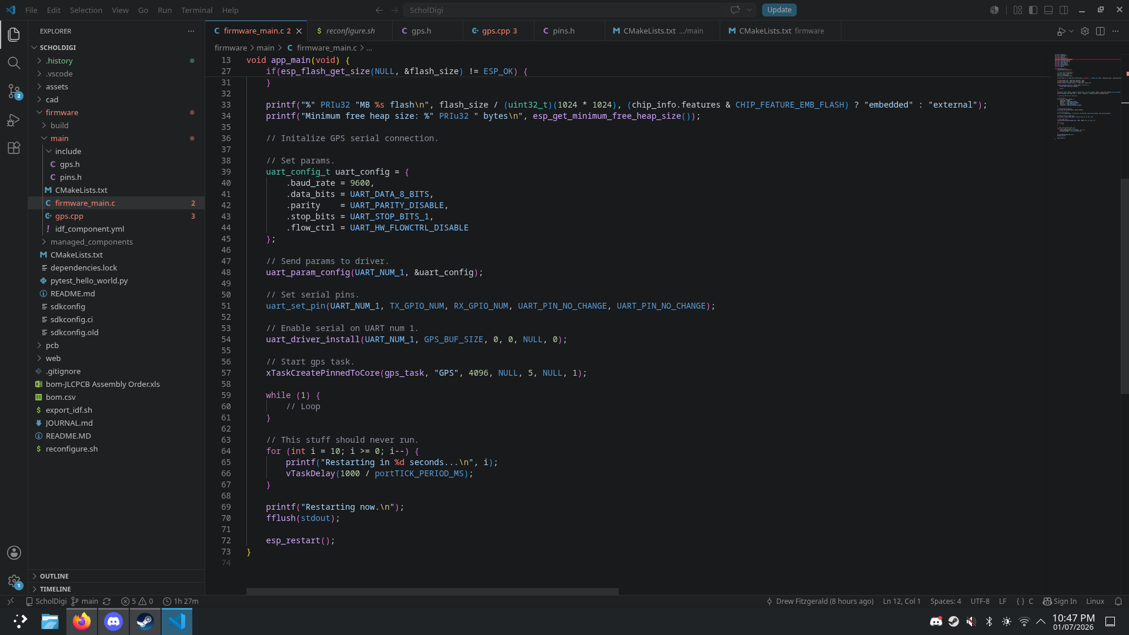
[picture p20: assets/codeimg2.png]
Code img2
  
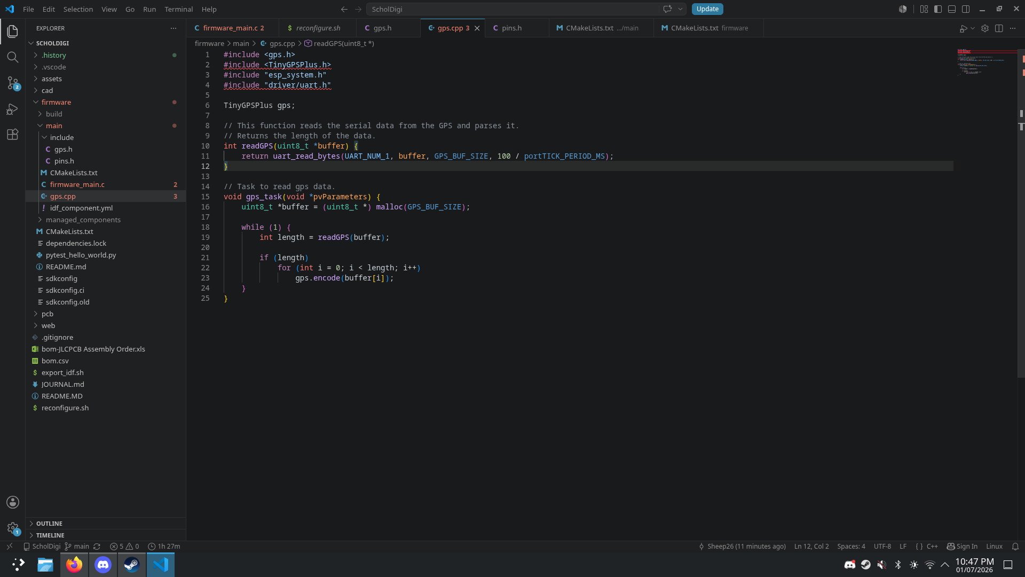
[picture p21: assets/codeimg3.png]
Code img3
  

## Entry 9 - 02/07/2026 - Time spent in session: 1 hour.
In this entry, I finished the GPS wrapper and added the configuration to set the time on the ESP32 based from the GPS.  
The reason I need a wrapper is because TinyGPSPlus is designed for C++, as a result it uses classes which means in my C objects, I can't reference TinyGPSPlus as the compiler won't know what to do with the classes.  
The solution I found was to have another C++ object sit between it and have the header file be designed for C, doing this the source file can be C++ and it can communicate with TinyGPSPlus and the main C object.  
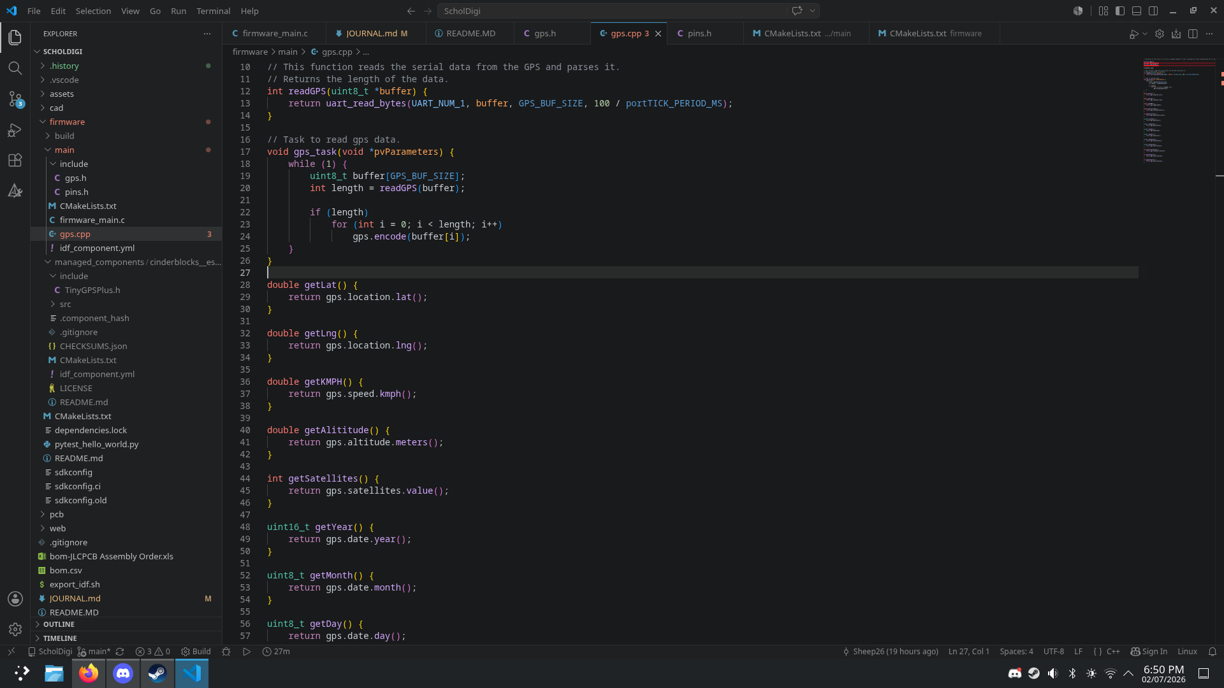
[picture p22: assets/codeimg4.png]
Code img4
  
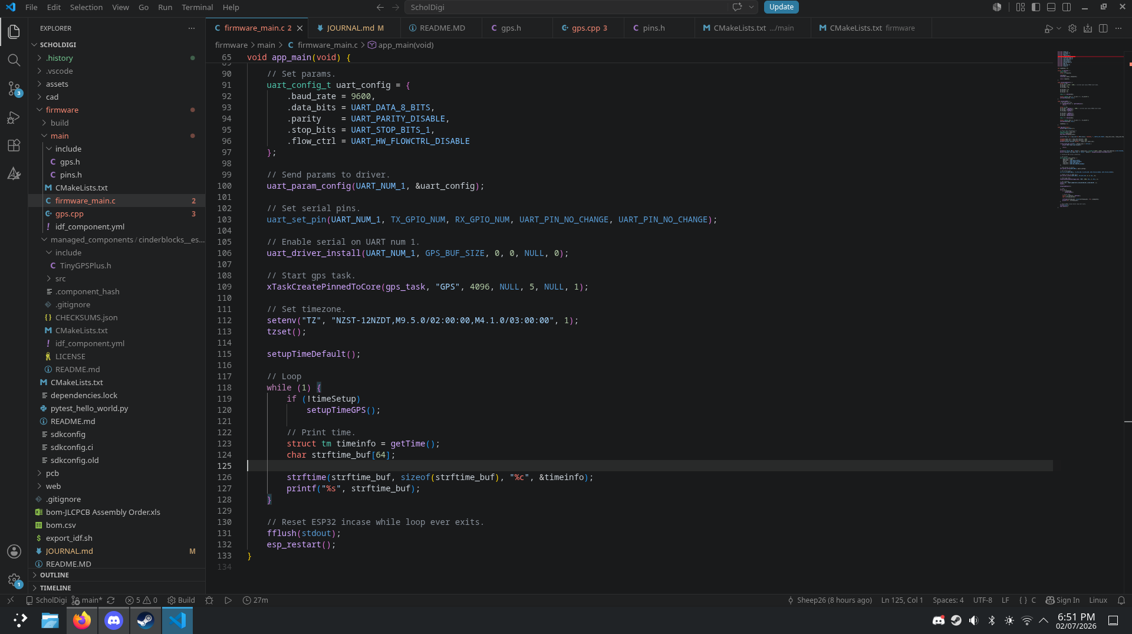
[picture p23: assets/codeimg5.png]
Code img5
  
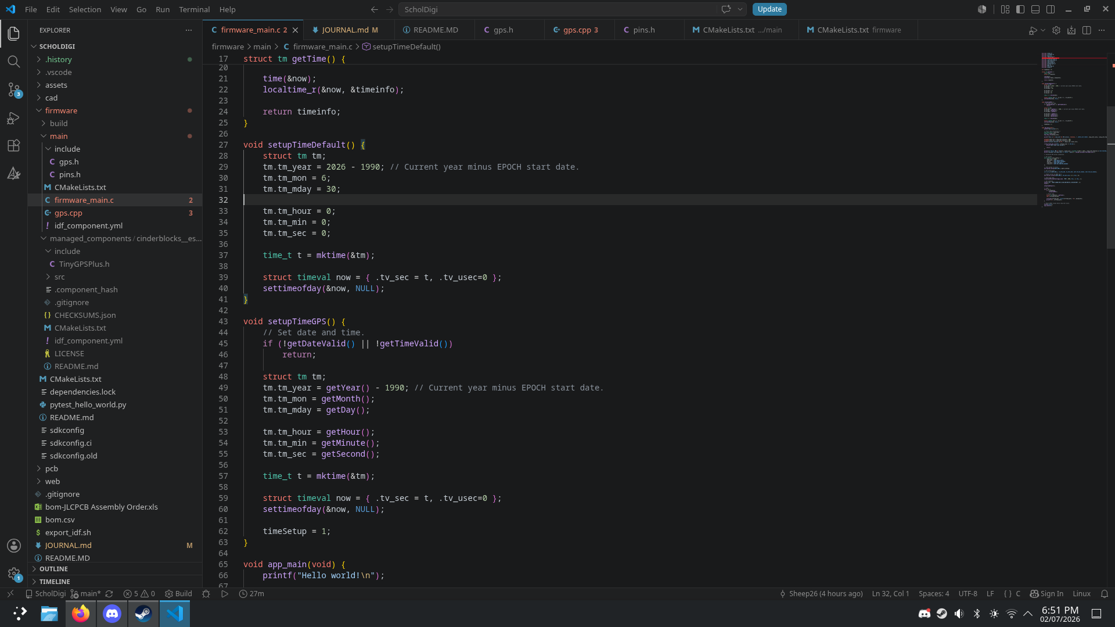
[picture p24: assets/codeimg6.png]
Code img6


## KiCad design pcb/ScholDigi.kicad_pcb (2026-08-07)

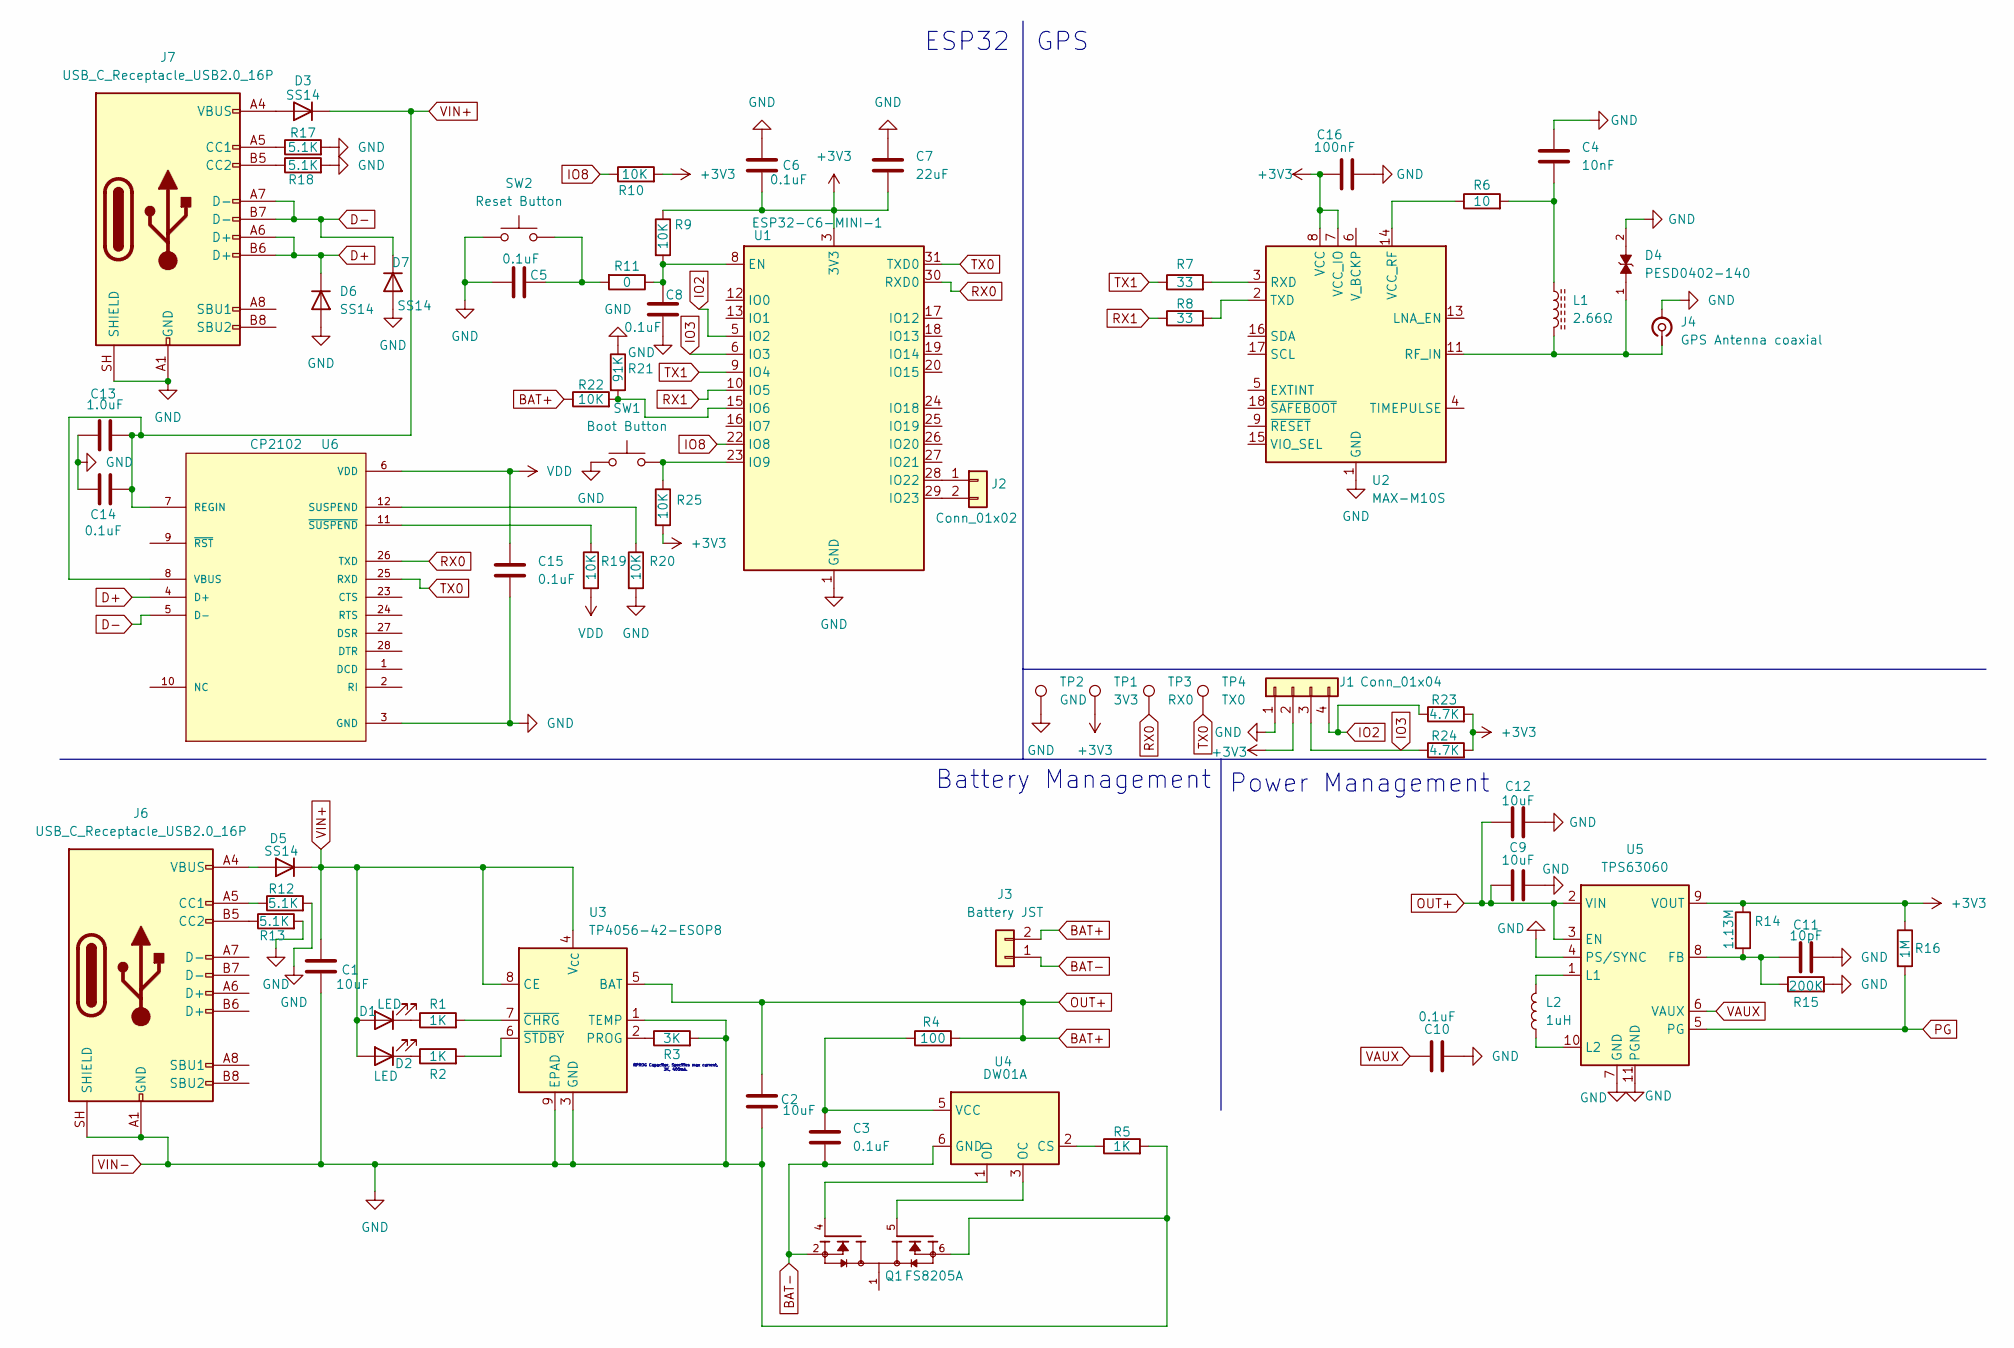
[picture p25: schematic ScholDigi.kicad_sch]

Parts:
C1, C2, C9, C12: 10uF; C_0603_1608Metric
C3, C5, C6, C8, C10, C14, C15: 0.1uF; C_0603_1608Metric
C4: 10nF; C_0603_1608Metric
C7: 22uF; C_0603_1608Metric
C11: 10pF; C_0603_1608Metric
C13: 1.0uF; C_0603_1608Metric
C16: 100nF; C_0603_1608Metric
D1, D2: LED; LED_0603_1608Metric
D3, D5, D6, D7: SS14; D_SMA
D4: PESD0402-140; DIO_PESD0402-140; PARTREV 2016
J1: Conn_01x04; SolderWire-0.5sqmm_1x04_P4.6mm_D0.9mm_OD2.1mm
J2: Conn_01x02; SolderWire-0.5sqmm_1x02_P4.6mm_D0.9mm_OD2.1mm
J3: Battery JST; JST_PH_B2B-PH-K_1x02_P2.00mm_Vertical
J4: GPS Antenna coaxial; U.FL_Hirose_U.FL-R-SMT-1_Vertical
J6, J7: USB_C_Receptacle_USB2.0_16P; USB_C_Receptacle_GCT_USB4105-xx-A_16P_TopMnt_Horizontal
L1: 2.66Ω; R_0603_1608Metric
L2: 1uH; L_0603_1608Metric
Q1: FS8205A; SOP65P640X120-8N; PARTREV 1.7
R1, R2, R5: 1K; R_0603_1608Metric
R3: 3K; R_0603_1608Metric
R4: 100; R_0603_1608Metric
R6: 10; R_0603_1608Metric
R7, R8: 33; R_0603_1608Metric
R9, R10, R19, R20, R22, R25: 10K; R_0603_1608Metric
R11: 0; R_0603_1608Metric
R12, R13, R17, R18: 5.1K; R_0603_1608Metric
R14: 1.13M; R_0603_1608Metric
R15: 200K; R_0603_1608Metric
R16: 1M; R_0603_1608Metric
R21: 91K; R_0603_1608Metric
R23, R24: 4.7K; R_0603_1608Metric
SW1: Boot Button; SW_SPST_TL3342
SW2: Reset Button; SW_SPST_TL3342
TP1: 3V3; TestPoint_Pad_D2.0mm
TP2: GND; TestPoint_Pad_D2.0mm
TP3: RX0; TestPoint_Pad_D2.0mm
TP4: TX0; TestPoint_Pad_D2.0mm
U1: ESP32-C6-MINI-1
U2: MAX-M10S; ublox_MAX
U3: TP4056-42-ESOP8; SOIC-8-1EP_3.9x4.9mm_P1.27mm_EP2.41x3.3mm_ThermalVias
U4: DW01A; SOT-23-6
U5: TPS63060; Texas_S-PWSON-N10_ThermalVias
U6: CP2102; QFN50P500X500X100-29N

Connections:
+3V3: C6.2, C7.2, C16.1, J1.2, R9.1, R10.2, R14.1, R16.1, R23.2, R24.2, R25.2, TP1.1 (1_1), U1.3 (3V3), U2.7 (VCC_IO), U2.8 (VCC), U5.9 (VOUT)
BAT+: C2.1, C9.1, C12.1, J3.2, R4.2, R22.1, U3.5 (BAT), U5.2 (VIN), U5.3 (EN)
BAT-: C3.2, J3.1, Q1.2, Q1.3, U4.6 (GND)
D+: D6.1 (K), J7.A6 (D+), J7.B6 (D+), U6.4 (D+)
D-: D7.1 (K), J7.A7 (D-), J7.B7 (D-), U6.5 (D-)
IO2: J1.4, R23.1, U1.5 (IO2)
IO3: J1.3, R24.1, U1.6 (IO3)
IO8: R10.1, U1.22 (IO8)
unnamed: C4.2, L1.1, R6.2
unnamed: C5.2, R11.2, SW2.2
unnamed: D1.1 (K), R1.1
unnamed: D2.1 (K), R2.1
unnamed: D3.2 (A), J7.A4 (VBUS), J7.A9 (VBUS), J7.B4 (VBUS), J7.B9 (VBUS)
unnamed: D5.2 (A), J6.A4 (VBUS), J6.A9 (VBUS), J6.B4 (VBUS), J6.B9 (VBUS)
unnamed: J2.1, U1.28 (IO22)
unnamed: J2.2, U1.29 (IO23)
unnamed: D4.1, J4.1 (In), L1.2, U2.11 (RF_IN)
unnamed: J6.A5 (CC1), R12.1
unnamed: J6.B5 (CC2), R13.1
unnamed: J7.A5 (CC1), R17.1
unnamed: J7.B5 (CC2), R18.1
unnamed: Q1.1, Q1.8
unnamed: C8.1, R9.2, R11.1, U1.8 (EN)
unnamed: R21.2, R22.2, U1.15 (IO6)
unnamed: R25.1, SW1.2, U1.23 (IO9)
unnamed: R7.2, U2.3 (RXD)
unnamed: R8.2, U2.2 (TXD)
unnamed: R6.1, U2.14 (VCC_RF)
unnamed: R3.1, U3.2 (PROG)
unnamed: R1.2, U3.7 (~CHRG)
unnamed: R2.2, U3.6 (~STDBY)
unnamed: R5.1, U4.2 (CS)
unnamed: Q1.5, U4.3 (OC)
unnamed: Q1.4, U4.1 (OD)
unnamed: C3.1, R4.1, U4.5 (VCC)
unnamed: C11.1, R14.2, R15.1, U5.8 (FB)
unnamed: L2.2, U5.1 (L1)
unnamed: L2.1, U5.10 (L2)
unnamed: U6.10 (NC), U6.13 (NC), U6.14 (NC), U6.15 (NC), U6.16 (NC), U6.17 (NC), U6.18 (NC), U6.19 (NC), U6.20 (NC), U6.21 (NC), U6.22 (NC)
unnamed: R20.1, U6.12 (SUSPEND)
unnamed: R19.1, U6.11 (~SUSPEND)
PG: R16.2, U5.5 (PG)
RX0: TP3.1 (1_1), U1.30 (RXD0), U6.26 (TXD)
RX1: R8.1, U1.10 (IO5)
TX0: TP4.1 (1_1), U1.31 (TXD0), U6.25 (RXD)
TX1: R7.1, U1.9 (IO4)
VAUX: C10.2, U5.6 (VAUX)
VDD: C15.1, R19.2, U6.6 (VDD)
VIN+: C1.1, C13.2, C14.2, D1.2 (A), D2.2 (A), D3.1 (K), D5.1 (K), U3.4 (V_{CC}), U3.8 (CE), U6.7 (REGIN), U6.8 (VBUS)
VIN-: C1.2, C2.2, C4.1, C5.1, C6.1, C7.1, C8.2, C9.2, C10.1, C11.2, C12.2, C13.1, C14.1, C15.2, C16.2, D4.2, D6.2 (A), D7.2 (A), J1.1, J4.2 (Ext), J6.A1 (GND), J6.A12 (GND), J6.B1 (GND), J6.B12 (GND), J6.SH (SHIELD), J7.A1 (GND), J7.A12 (GND), J7.B1 (GND), J7.B12 (GND), J7.SH (SHIELD), Q1.6, Q1.7, R3.2, R5.2, R12.2, R13.2, R15.2, R17.2, R18.2, R20.2, R21.1, SW1.1, SW2.1, TP2.1 (1_1), U1.1 (GND), U1.2 (GND), U1.11 (GND), U1.14 (GND), U1.36 (GND), U1.37 (GND), U1.38 (GND), U1.39 (GND), U1.40 (GND), U1.41 (GND), U1.42 (GND), U1.43 (GND), U1.44 (GND), U1.45 (GND), U1.46 (GND), U1.47 (GND), U1.48 (GND), U1.49 (GND), U1.50 (GND), U1.51 (GND), U1.52 (GND), U1.53 (GND), U2.1 (GND), U2.10 (GND), U2.12 (GND), U3.1 (TEMP), U3.3 (GND), U3.9 (EPAD), U5.4 (PS/SYNC), U5.7 (GND), U5.11 (PGND), U6.3 (GND), U6.29 (GND)

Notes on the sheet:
RPROG Capacitor, Specifies max current. 3K, 400mA.
Power Management
Battery Management
GPS
ESP32

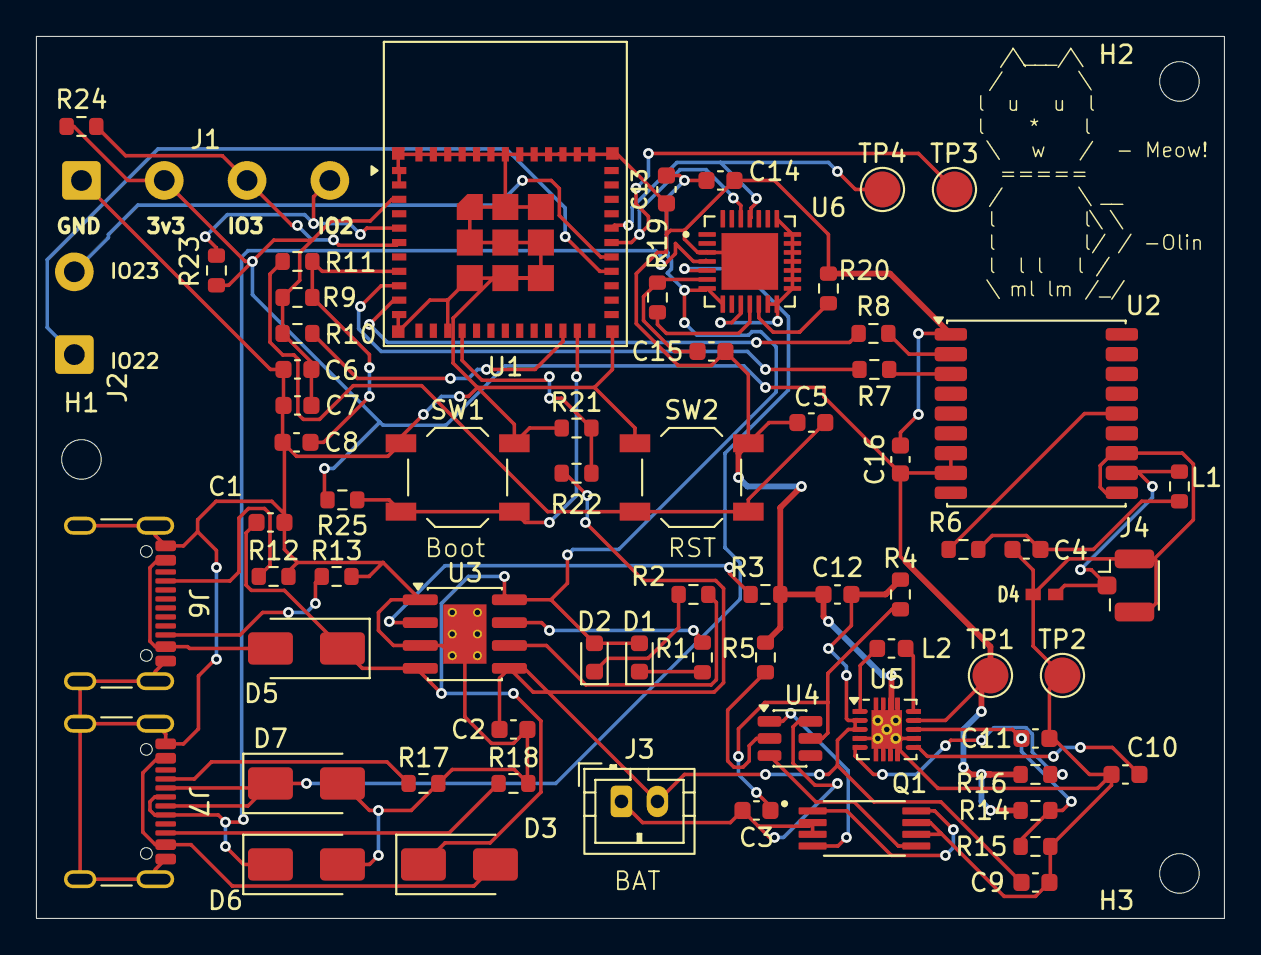
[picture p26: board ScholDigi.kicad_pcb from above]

Board: 2 copper layers, 66.0 x 49.0 mm, 72 parts (0 on the bottom side), 50 nets.

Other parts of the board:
H1, H2, H3: MountingHole_2.2mm_M2

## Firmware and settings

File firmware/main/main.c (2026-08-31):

#include <stdio.h>
#include <inttypes.h>
#include <pins.h>
#include <gps.h>
#include <sys/time.h>
#include <time.h>
#include <exercise.h>
#include <ssd1306.h>
#include <haversine.h>
#include <esp_littlefs.h>
#include <config.h>
#include <gpio.h>
#include "sdkconfig.h"
#include "freertos/FreeRTOS.h"
#include "freertos/task.h"
#include "esp_chip_info.h"
#include "esp_flash.h"
#include "esp_system.h"
#include "driver/uart.h"
#include "driver/i2c_master.h"

int timeSetup = 0;
int locationValid = 0;
int sleeping = 0;
struct tm lastButtonPress;

exercise_t *current_exercise;
i2c_master_bus_handle_t i2c_bus_handle;

ssd1306_handle_t ssd1306_handle;

void check_i2c(uint8_t addr) {
    esp_err_t err = i2c_master_probe(i2c_bus_handle, addr, 100);

    if (err == ESP_OK) {
        printf("Found device at 0x%02X\n", addr);

        return;
    }

    printf("Device not found 0x%02X\n", addr);
}

void scan_i2c() {
    printf("I2C Scan starting.\n");

    for (uint8_t addr = 0x08; addr < 0x78; addr++)
        check_i2c(addr);
}

struct tm getTime() {
    time_t now;
    struct tm timeinfo;

    time(&now);
    localtime_r(&now, &timeinfo);

    return timeinfo;
}

void setupTimeGPS() {
    // Set date and time.
    if (!getDateValid() || !getTimeValid())
        return;

    struct tm tm;
    tm.tm_year = getYear() - 1990; // Current year minus EPOCH start date.
    tm.tm_mon = getMonth();
    tm.tm_mday = getDay();

    tm.tm_hour = getHour();
    tm.tm_min = getMinute();
    tm.tm_sec = getSecond();

    time_t t = mktime(&tm);

    struct timeval now = { .tv_sec = t, .tv_usec=0 };
    settimeofday(&now, NULL);

    lastButtonPress = tm;
    timeSetup = 1;
}

void app_main(void) {
    /* Print chip information */
    esp_chip_info_t chip_info;
    uint32_t flash_size;
    esp_chip_info(&chip_info);

    printf("This is %s chip with %d CPU core(s), %s%s%s%s, ", CONFIG_IDF_TARGET, chip_info.cores, (chip_info.features & CHIP_FEATURE_WIFI_BGN) ? "WiFi/" : "", (chip_info.features & CHIP_FEATURE_BT) ? "BT" : "", (chip_info.features & CHIP_FEATURE_BLE) ? "BLE" : "", (chip_info.features & CHIP_FEATURE_IEEE802154) ? ", 802.15.4 (Zigbee/Thread)" : "");

    unsigned major_rev = chip_info.revision / 100;
    unsigned minor_rev = chip_info.revision % 100;
    printf("silicon revision v%d.%d, ", major_rev, minor_rev);

    if(esp_flash_get_size(NULL, &flash_size) != ESP_OK) {
        printf("Get flash size failed");

        return;
    }

    printf("%" PRIu32 "MB %s flash\n", flash_size / (uint32_t)(1024 * 1024), (chip_info.features & CHIP_FEATURE_EMB_FLASH) ? "embedded" : "external");
    printf("Minimum free heap size: %" PRIu32 " bytes\n", esp_get_minimum_free_heap_size());

    // Setup littlefs.
    esp_vfs_littlefs_conf_t fs_conf = {
        .base_path = "/littlefs",
        .partition_label = "fs_storage",
        .format_if_mount_failed = 1,
        .dont_mount = 0
    };

    /*ESP_ERROR_CHECK(esp_vfs_littlefs_register(&fs_conf));

    size_t total = 0, used = 0;
    ESP_ERROR_CHECK(esp_littlefs_info(fs_conf.partition_label, &total, &used));

    printf("Total flash storage: %d, Used flash storage: %d", total, used);*/

    // Initalize GPS serial connection.
    uart_config_t uart_config = {
        .baud_rate = 9600,
        .data_bits = UART_DATA_8_BITS,
        .parity    = UART_PARITY_DISABLE,
        .stop_bits = UART_STOP_BITS_1,
        .flow_ctrl = UART_HW_FLOWCTRL_DISABLE
    };

    // Enable serial on UART num 1.
    ESP_ERROR_CHECK(uart_param_config(UART_NUM_1, &uart_config));
    ESP_ERROR_CHECK(uart_set_pin(UART_NUM_1, TX_GPIO_NUM, RX_GPIO_NUM, UART_PIN_NO_CHANGE, UART_PIN_NO_CHANGE));
    ESP_ERROR_CHECK(uart_driver_install(UART_NUM_1, GPS_BUF_SIZE, 0, 0, NULL, 0));

    // Setup I2C for Display and GPIO.
    i2c_master_bus_config_t i2c_bus_config = {
        .i2c_port = I2C_NUM_0,
        .sda_io_num = I2C_SDA,
        .scl_io_num = I2C_SCL,
        .clk_source = I2C_CLK_SRC_DEFAULT,
        .glitch_ignore_cnt = 7,
    };

    // Set I2C master bus.
    ESP_ERROR_CHECK(i2c_new_master_bus(&i2c_bus_config, &i2c_bus_handle));

    // Debug function.
#ifdef DEBUG
    check_i2c(PCF_I2C_ADDR);
    check_i2c(I2C_SSD1306_DEV_ADDR);
#endif

    //setup_gpio();

#ifdef DISPLAY
    ssd1306_config_t ssd1306_config = I2C_SSD1306_128x64_CONFIG_DEFAULT;
    ssd1306_init(i2c_bus_handle, &ssd1306_config, &ssd1306_handle);

    if (ssd1306_handle == NULL) {
        printf("SSD1306 handle init failed");
        assert(ssd1306_handle);
    }

    ssd1306_clear_display(ssd1306_handle, false);
    ssd1306_set_contrast(ssd1306_handle, 0xFF);
#endif

    // Start gps task.
    //xTaskCreatePinnedToCore(GPSTask, "GPS", 4096, NULL, 5, NULL, 0);
    GPSTask(NULL);
    // Set timezone.
    setenv("TZ", "NZST-12NZDT,M9.5.0/02:00:00,M4.1.0/03:00:00", 1);
    tzset();

    struct timeval now = { .tv_sec = 1782734400, .tv_usec=0 };
    settimeofday(&now, NULL);

    lastButtonPress = getTime();

    // Loop
    while (1) {
        if (!timeSetup)
            setupTimeGPS();

        struct tm current_time = getTime();
        time_t time_epoch = mktime(&current_time);

#ifdef DISPLAY
        if (time_epoch - mktime(&lastButtonPress) > 300 && !sleeping) {
            sleeping = 1;

            ssd1306_disable_display(ssd1306_handle); // Put display to sleep after 5 minutes of no button presses.
        }

        if ((!digital_read(WAKE_PIN) || !digital_read(START_PIN)) && sleeping) {
            sleeping = 0;
            lastButtonPress = getTime();

            ssd1306_enable_display(ssd1306_handle);
        }
#endif

        if (!digital_read(START_PIN)) {
            if (!current_exercise)
                current_exercise = (exercise_t*) calloc(1, sizeof(exercise_t));
            else {
                // Handle putting exercise into storage eventually.
                exercise_point_t *p = current_exercise->list;
                exercise_point_t *l = (void*) 0;

                int div = 0;

                while (p) {
                    // Add exercise distance.
                    if (l) {
                        current_exercise->distance += distanceBetweenPoints(l, p);

                        l = (void*) 0;
                    } else
                        l = p;

                    current_exercise->max_alt = p->alt > current_exercise->max_alt ? p->alt : current_exercise->max_alt;
                    current_exercise->min_alt = (p->alt < current_exercise->min_alt || !current_exercise->min_alt) ? p->alt : current_exercise->min_alt;
                    current_exercise->top_speed = p->speed > current_exercise->top_speed ? p->speed : current_exercise->top_speed;

                    current_exercise->alt_diff = current_exercise->max_alt - current_exercise->min_alt;
                    current_exercise->avg_alt += p->alt;
                    current_exercise->avg_speed += p->speed;

                    div++;                    
                    p = p->next;
                }

                current_exercise->avg_alt = current_exercise->avg_alt / div;
                current_exercise->avg_speed = current_exercise->avg_speed / div;

                current_exercise->stop = time_epoch;
                // We have calculated all our things so we need to store it now.

                printf("Distance: %f", current_exercise->distance);

                // Free exercise from memory.
                exercise_point_t *pointah = current_exercise->list;

                while (pointah) {
                    exercise_point_t *next = p->next;

                    free(pointah);
                    pointah = next;
                }

                free(current_exercise);
                current_exercise = (void*) 0; // Set current exercise to null instead of having it reference unallocated memory.
            }

            vTaskDelay(pdMS_TO_TICKS(10));
        }

        //printf("Satellites: %d\n", getSatellites());

        // Print time.
        char strftime_buf[64];

        //strftime(strftime_buf, sizeof(strftime_buf), "%c", &current_time);
        //printf("%s\n", strftime_buf);


        char buffy[64];
        snprintf(buffy, sizeof(buffy), "Lat: %f\nLng: %f", getLat(), getLng());

#ifdef DISPLAY
        ssd1306_clear_display(ssd1306_handle);
        ssd1306_display_text(ssd1306_handle, 0, buffy, false);
#endif

        if (current_exercise && getLocationValid() && getSatellites()) {
            // Check if things have changed or if there just hasn't been a point yet.
            if (!current_exercise->list || !current_exercise->last || getLat() != current_exercise->last->lat || getLng() != current_exercise->last->lng || getAlititude() != current_exercise->last->alt) {
                // Create pointer for exercise point struct.
                exercise_point_t *point = (exercise_point_t*) malloc(sizeof(exercise_point_t));
                assert(point);

                // Set variables.
                if (!current_exercise->start)
                    current_exercise->start = time_epoch;

                point->lat = getLat();
                point->lng = getLng();
                point->alt = getAlititude();
                point->speed = getSpeed();
                point->time = time_epoch;

                // Add point.
                addExercisePoint(current_exercise, point);
            }
        }
    }

    // Reset ESP32 incase while loop ever exits.
    esp_vfs_littlefs_unregister(fs_conf.partition_label);
    ssd1306_delete(ssd1306_handle);
    fflush(stdout);
    esp_restart();
}

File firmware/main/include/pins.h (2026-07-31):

#ifndef PINS_H
#define PINS_H

#include <config.h>

#define TX_GPIO_NUM 4
#define RX_GPIO_NUM 5

#define I2C_SDA 2
#define I2C_SCL 3

#define PCF_I2C_ADDR 0x20

#define HIGH 0x01
#define LOW 0x00

#ifdef PCF
#define WAKE_PIN 0
#define START_PIN 1
#define DEBUG_PIN 2
#else
#define WAKE_PIN 0
#define START_PIN 1
#define DEBUG_PIN 2
#endif

#endif

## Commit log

2026-06-18 Some work
    [ScholDigi.kicad_sch]
2026-06-18 A few things
    [ScholDigi.kicad_sch]
2026-06-18 Add Uart connector
    [ScholDigi.kicad_sch]
2026-06-18 Sort out footprints
    [ScholDigi.kicad_sch]
2026-06-21 PCB stuff
    [ScholDigi.kicad_pcb]
2026-06-22 PCB and PCB routes and PCB organisation
    [ScholDigi.kicad_pcb, ScholDigi.kicad_sch]
2026-06-22 Move small things
    [ScholDigi.kicad_pcb]
2026-06-22 Add little kitty
    [ScholDigi.kicad_pcb]
2026-06-22 Button Text
    [ScholDigi.kicad_pcb]
2026-06-22 Mounting holes
    [ScholDigi.kicad_pcb]
2026-06-22 No drc errors now
    [ScholDigi.csv, ScholDigi.kicad_pcb, ScholDigi.kicad_sch]
2026-06-22 Rah BOM
    [ScholDigi.csv]
2026-06-23 change jst connector
    [ScholDigi.kicad_pcb, ScholDigi.kicad_sch]
2026-06-23 Change BOM
    [ScholDigi.csv]
2026-06-24 Rah, testpoints for display
    [ScholDigi.kicad_pcb, ScholDigi.kicad_sch]
2026-06-24 MAjor tung
    [ScholDigi.kicad_pcb]
2026-06-24 Display header are now through hole solders
    [ScholDigi.kicad_pcb, ScholDigi.kicad_sch]
2026-06-25 CHanges so that i can get battery voltage
    [ScholDigi.kicad_pcb, ScholDigi.kicad_sch]
2026-06-26 add funnies
    [ScholDigi.kicad_pcb]
2026-06-26 Changes to fix DRC
    [ScholDigi.kicad_pcb]
2026-06-26 small changes
    [ScholDigi.kicad_pcb, ScholDigi.kicad_sch]
2026-06-26 Change usb
    [ScholDigi.kicad_pcb, ScholDigi.kicad_sch]
2026-06-28 Inspirational quote
    [ScholDigi.kicad_pcb]
2026-07-02 Update board 3d model
2026-07-02 Add images, work on readme
    [case.stl]
2026-07-03 i hope this is good enough
    [bom-JLCPCB Assembly Order.csv, bom-JLCPCB Assembly Order.xls]
2026-07-03 Update bom-JLCPCB Assembly Order.csv
    [bom-JLCPCB Assembly Order.csv]
2026-07-03 Update bom-JLCPCB Assembly Order.xls
    [bom-JLCPCB Assembly Order.xls]
2026-07-03 Edit BOM
    [bom.csv, designators.csv, positions.csv]
2026-07-12 Add i2c to cmake list
2026-07-22 Add pullups
    [ScholDigi.kicad_pcb]
2026-07-22 more io
    [ScholDigi.kicad_pcb, ScholDigi.kicad_sch]
2026-07-22 Clean up board
    [ScholDigi.kicad_pcb]
2026-07-22 Fix silkscreen
    [ScholDigi.kicad_pcb]
2026-07-22 Pullup boot button
    [ScholDigi.kicad_pcb, ScholDigi.kicad_sch]
2026-07-24 Fix pcb
    [ScholDigi.kicad_pcb, ScholDigi.kicad_sch]
2026-07-24 Fix GPS
    [ScholDigi.kicad_pcb, ScholDigi.kicad_sch]
2026-07-31 like genuinly why doesn't it compile
    [gpio.c, gps.cpp, pins.h]
